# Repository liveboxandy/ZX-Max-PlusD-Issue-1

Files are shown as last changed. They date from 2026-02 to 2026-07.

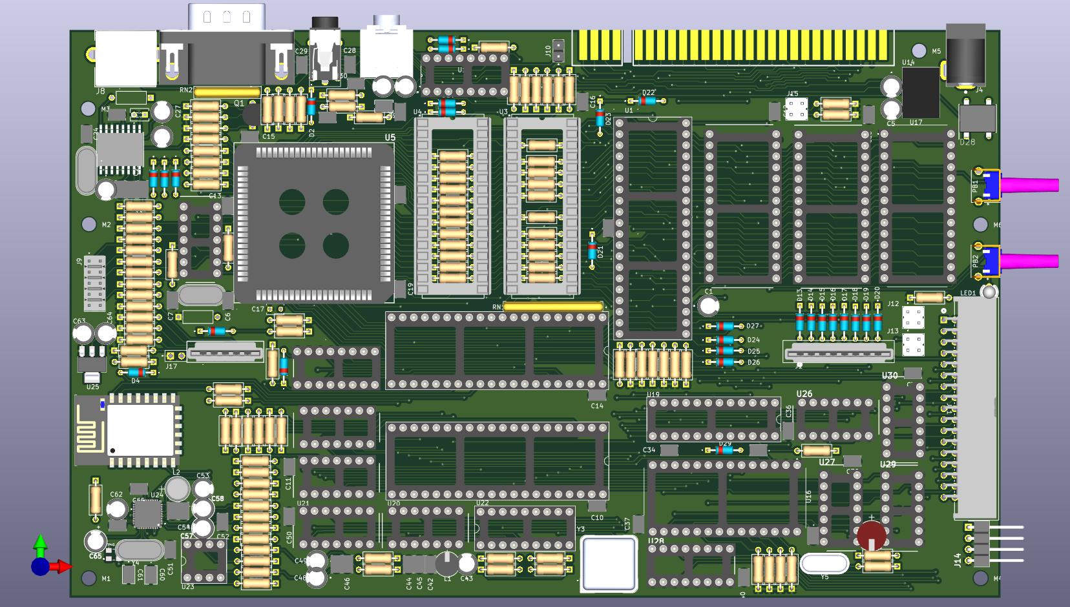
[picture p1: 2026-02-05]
ZX Max 128 PlusD Issue1.jpg

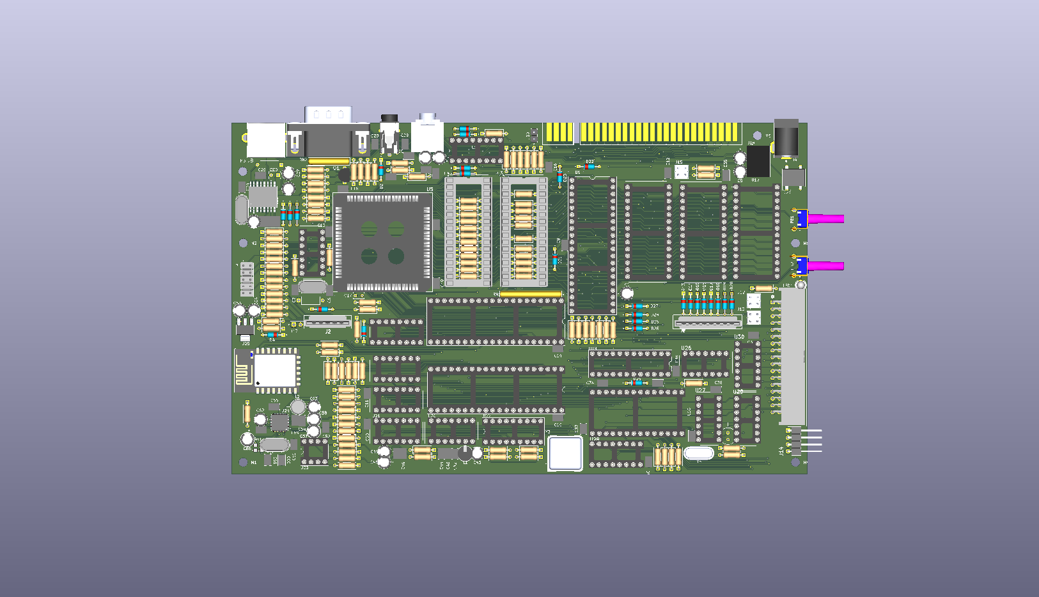
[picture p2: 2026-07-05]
ZX Max 128 PlusD Issue1.png

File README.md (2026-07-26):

This is a recreation of the ZX Max Plus D Issue 1 PCB as designed by DonSuperfo but done in KiCAD 10.

This was only done in order to create an interactive BOM (in the BOM folder) to assist in the assembling of the PCB.

The KiCAD schematics 'should' be correct but nothing should be assumed as correct without checking with the original schematic and PCB layout. Although I have followed the original track and via layout further checking should be done before using these files to order a pcb with. Currently I would still order the pcb from PCBWay using the link from https://github.com/DonSuperfo/ZX-Max-128

Note that any part number for any device used in this project might not be the correct one from the original BOM as supplied from PCBWay as I had to change some parts to get a footprint that would fit in the space on the original pcb with the correct pin spacing. This required selecting a different part number or vendor. This applies mainly to capacitors. Some other parts are no longer available under that number from Digikey.

As always, measure twice and order one.

Use at your own risk.

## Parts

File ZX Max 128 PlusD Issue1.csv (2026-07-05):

Source: | E:\Kicad\ZX Max 128 PlusD\ZX Max 128 PlusD Issue1.kicad_sch
Date: | 2026-07-05T10:47:33
Tool: | Eeschema 10.0.4
Generator: | C:\Program Files\KiCad\7.0\bin\scripting\plugins/bom_csv_grouped_by_value_with_fp.py
Component Count: | 266
Ref | Qnty | Value | Cmp name | Footprint | Description | Vendor | DNP
C1, C2, C3, C4, C26, C48, C49, C53, C62, C63, C64 | 11 | 10uF 25V | ECA-1EM100B | Mod:CAPPRD200W50D500H1100 | ECA-1EM100B - 10uF Aluminum Electrolytic Capacitors Radial
C5, C43 | 2 | 22uF 16V | ECA-1EM100B | Mod:CAPPRD200W50D500H1100 | ECA-1EM100B - 10uF Aluminum Electrolytic Capacitors Radial
C6, C7 | 2 | 27pF | FG18C0G1H270JNT06 | Mod:CAPRB250W50L400T250H550
C8, C27 | 2 | 220uF 16V | 16YXJ220MT16.3X11 | Mod:CAPPRD200W50D500H1100
C9, C10, C11, C12, C13, C14, C15, C16, C17, C18, C19, C20, C21, C22, C23, C24, C25, C28, C29, C30, C34, C35, C36, C37, C38, C39, C40, C42, C50, C51, C52, C54, C55, C56, C59 | 35 | 100nF | K104Z15Y5VF5TL2 | Mod:CAPRB250W50L400T250H550 | Vishay K 100nF Ceramic Multilayer Capacitor, 100 V dc, +85C, Y5V Dielectric, +80 %, -20 %
C31, C44, C45, C46, C47 | 5 | 10nF 50V | K104Z15Y5VF5TL2 | Mod:CAPRB250W50L400T250H550 | Vishay K 100nF Ceramic Multilayer Capacitor, 100 V dc, +85C, Y5V Dielectric, +80 %, -20 %
C32 | 1 | 3n3 50V | K104Z15Y5VF5TL2 | Mod:CAPRB250W50L400T250H550 | Vishay K 100nF Ceramic Multilayer Capacitor, 100 V dc, +85C, Y5V Dielectric, +80 %, -20 %
C33 | 1 | 3n3 50V | K104Z15Y5VF5TL2 | Mod:CAPRB250W50L400T250H550 | Vishay K 100nF Ceramic Multilayer Capacitor, 100 V dc, +85C, Y5V Dielectric, +80 %, -20 % |  | DNP
C41 | 1 | 33pF 100V | K330J10C0GH5TL2 | Mod:K101J15C0GF53L2 | Capacitor 33pF 100V
C57, C58 | 2 | 100uF 16V | WCAP-ATG8_5X11 | Mod:WCAP-ATG8_5X11_DXL_
C60, C61 | 2 | 22pF 50V | K220J15C0GF53L2 | Mod:CAP_K220J15C0GF53L2_VIS
C65 | 1 | 1uF 63V | WCAP-ATG5_5X11 | Mod:WCAP-ATG5_5X11_DXL_ | Capacitor 1uF 63V
C66 | 1 | 100pF 50V | K101J15C0GF53L2 | Mod:K101J15C0GF53L2 | Capacitor 100pF 50V
C67 | 1 | 100uF 35V | 35YXJ100M6.3X11 | Mod:CAP_YX_6P3X11_RUB | Capacitor 100uF 35V
D1, D2, D4, D5, D6, D7, D8, D9, D10, D11, D12, D13, D14, D15, D16, D17, D18, D19, D20, D21, D22, D23, D24, D25, D26, D27, D29 | 27 | 1N4148 | 1N4148 | Mod:DIOAD753W49L380D172B | Diode 1N4148
D28 | 1 | DF02M | DF02M | Mod:DIP825W58P510L832H543Q4N | Bridge Rectifier DF02M 1A
J1 | 1 | 8 Pin FFC Connector | 5-520315-8 | Mod:55203155 | Connector FFC Socket 8 Pin
J2 | 1 | 5 Pin FFC Connector | 5-520315-5 | Mod:55203155 | Connector FFC Socket 5 Pin
J3 | 1 | ZX_48K_EDGE | ZX_48K_EDGE | Mod:ZX_BUS_B_TOP | ZX Spectrum 48K Edge Connector
J4 | 1 | PJ-002A | PJ-002A | Mod:CUI_PJ-002A
J5 | 1 | AV Jack | AudioJack3 | Mod:PJ-322A | AV Jack PJ-322
J6 | 1 | Connector Audio 3525N | SJ1-3525N | Mod:CUI_SJ1-3525N | Connector Audio 3525N
J7 | 1 | A-DS_09_A_KG-T4S | A-DS_09_A_KG-T4S | Mod:ASSMANN_A-DS_09_A_KG-T4S | 9-pin D-SUB connector, pins (male), Mounting Hole
J8 | 1 | Connector 9 Pin Mini DIN | KMDGX-9S-BS-1 | Mod:KMDGX9SBS1 | Connector 9 Pin MiniDin
J9 | 1 | Header 5x2 | 10129381-910002BLF | Mod:AMPHENOL_10129381-910002BLF | Header 5x2
J10, J17 | 2 | Header 2x1 | M20-9990246 | Mod:HARWIN_M20-9990246
J11 | 1 | FDC Connector | 5103311-7 | Mod:CONN_5103311-7_TYC | Connector 17x2 RA
J12, J13 | 2 | Header 2x2 | PH2-04-UA | Mod:ADAM_PH2-04-UA | Header 2x2
J14 | 1 | Header 4 Pin FDD Power | SWR25X-NRTC-S04-RB-BA | Mod:HDRRA4W64P0X254_1X4_1016X320X610P | Header 4 Pin FDD Power
J15 | 1 | PlusD ROM | PH2-04-UA | Mod:ADAM_PH2-04-UA | Header 2x2
L1, L2 | 2 | 220uH | RLB0608-221KL | Mod:IND_BOURNS_RLB0608
LED1 | 1 | LED Red 3MM | WL-TMRC_3MM | Mod:WL-TMRC_3MM | LED Red 3MM
PB1 | 1 | Switch 6x6 RA | 2-1825027-0 | Mod:SW2_1825027-G_TEC
PB2 | 1 | NMI | 2-1825027-0 | Mod:SW2_1825027-G_TEC | Switch 6mm x 6mm RA
Q1 | 1 | Transistor BC548 | BC548BTA | Mod:BC548BTA
R1, R2, R3, R4, R5, R6, R7, R8, R9, R10, R11, R12, R13, R14, R15, R16, R17, R18, R19, R20, R21, R22, R27, R28, R29, R54, R57, R58, R78, R81, R82, R83, R84, R85, R86 | 35 | 470R | CF14JT470R | Mod:STA_CF14_STP | 470R
R23, R24, R25, R26, R46, R47, R48, R49, R50, R55, R56, R73, R75, R77, R79, R80, R92, R93, R96, R97, R100, R103, R112 | 23 | 10K0 | CF14JT10K0 | Mod:STA_CF14_STP | 10K0
R30, R31, R32, R33 | 4 | 75R0 | CF14JT75R0 | Mod:STA_CF14_STP | 75R0
R34 | 1 | 2K70 | CF14JT2K70 | Mod:STA_CF14_STP | 2K70 |  | DNP
R35, R36, R37, R38, R39 | 5 | 68R0 | CF14JT68R0 | Mod:STA_CF14_STP | 68R0
R40, R41, R42, R43, R44, R45 | 6 | 150R | CF14JT150R | Mod:STA_CF14_STP | 150R
R51 | 1 | 1M00 | CF14JT1M00 | Mod:STA_CF14_STP | 1M00
R52, R59, R62, R63, R64, R65, R68, R69, R70, R94, R95, R98, R99 | 13 | 1K00 | CF14JT1K00 | Mod:STA_CF14_STP | 1K00
R53 | 1 | 4K70 | CF14JT4K70 | Mod:STA_CF14_STP | 4K70 |  | DNP
R60, R61, R66, R67, R90, R91, R102, R105 | 8 | 2K20 | CF14JT2K20 | Mod:STA_CF14_STP | 2K20
R71 | 1 | 33K0 | CF14JT33K0 | Mod:STA_CF14_STP | 33K0
R72, R74 | 2 | 150K | CF14JT150K | Mod:STA_CF14_STP | 150K
R76 | 1 | 470K | CF14JT470K | Mod:STA_CF14_STP | 470K
R87, R88 | 2 | 270R | CF14JT270R | Mod:STA_CF14_STP | 270R
R101, R104, R108, R109 | 4 | 24K0 | CF14JT24K0 | Mod:STA_CF14_STP | 24K0
R106, R110, R111 | 3 | 47K0 | CF14JT47K0 | Mod:STA_CF14_STP | 47K0
R107 | 1 | 27K0 | CF14JT27K0 | Mod:STA_CF14_STP | 27K0
RN1 | 1 | 10K | 4609X-101-103LF | Mod:SIP249W50P254L2281H508Q9
RN2 | 1 | 10K | 4606X-101-103LF | Mod:4606X-101-103LF
U1 | 1 | Z80 | Z84C0010PEG | Mod:Z80_Socket | Z80 CPU
U2, U18 | 2 | EEPROM/EPROM 32Kx8 | AT27C256R-45PU | Mod:DIP1556W56P254L3702H483Q28N | EEPROM/EPROM 32Kx8
U3, U4 | 2 | AS6C1008-55PCN | AS6C1008-55PCN | Mod:PDIP-32_MIL600_ALL
U5 | 1 | EPM7128SLC | PLCC-84-AT | Mod:PLCC84AT | EPM7128SLC-84 PLCC Socket
U6 | 1 | 74HC04 | 74HC04_1 | Mod:DIP794W53P254L1930H508Q14N | Hex Inverter
U7 | 1 | SN74HC174N | SN74HC174N | Mod:DIP794W53P254L1930H508Q16N | Hex D flip-flop w/reset,SN74HC174N DIP16
U8, U9 | 2 | AY-3-8910 | AY-3-8910_1 | Mod:Z80_Socket | AY-3-8910 Sound Synth
U10, U20 | 2 | CD74HC30E | CD74HC30E_1 | Mod:DIP794W53P254L1930H508Q14N | NAND, 8-Input
U11 | 1 | 74HC74 | 74HC74 | Mod:DIP794W53P254L1930H508Q14N | Dual D Flip-flop, Set & Reset
U12 | 1 | CD74HC366E | CD74HC366E | Mod:CD74HC366E | Hex Buffer Inverting Tri-State
U13 | 1 | AD724JRZ | AD724JRZ | Mod:RW_16_ADI | RGB - PAL Encoder
U14 | 1 | R-78E5.0-1.0 | R-78E5.0-1.0 | Mod:CONV_R-78E5.0-1.0
U15 | 1 | ESP8266-12E | ESP8266-12E | Mod:WIFI_Module_ESP8266_12E | ESP8266-12E Bluetooth Module
U16 | 1 | WD1772 | WD1772 | Mod:DIP1555W45P254L3733H482Q28
U17 | 1 | AS6C6264-55PCN | AS6C6264-55PCN | Mod:DIP1555W45P254L3733H482Q28 | SRAM 64Kx8
U19 | 1 | GAL20V8B | GAL20V8B | Mod:DIP-24_W7.62mm_Socket | Hex D FlipFlop
U21 | 1 | 74HC32 | 74HC32 | Mod:DIP794W53P254L1930H508Q14N
U22 | 1 | Sound Generator SAA1099 | SAA1099 | Mod:DIP-18_W7.62mm_Socket | Sound Generator SAA1099
U23 | 1 | MCP602-I/P | MCP602 | Mod:DIP-8_W7.62mm_Socket | MCP602-I/P Dual Op Amp 8 Pin
U24 | 1 | SAM2695 | SAM2695 | Mod:QFN40P600X600X90-49N | MIdi Generator SAM2695
U25 | 1 | 3V3 1Amp | AZ1117IH-3.3TRG1 | Mod:SOT230P700X185-4N | Voltage Regulator 3V3 1Amp
U26 | 1 | 74HC27 | 74HC27 | Mod:DIP794W53P254L1930H508Q14N | NOR, 3-Input, Triple
U27 | 1 | 74HC00 | 74HC00 | Mod:DIP794W53P254L1930H508Q14N | NAND, 2-Input, Quad
U28 | 1 | SN74LS175NE4 | SN74LS175NE4 | Mod:DIP794W53P254L1930H508Q16N | Flip Flops Quadruple D-Type Flip-Flop W/Clear
U29 | 1 | SN74LS06 | SN74LS06 | Mod:DIP794W53P254L1930H508Q14N | Hex Inverter
U30 | 1 | 74HC126 | 74HC126 | Mod:DIP794W53P254L1930H508Q14N | Buffer, Quad, 3-State
Y1 | 1 | 28.375Mhz | Crystal | Mod:Crystal_HC49-4H_Vertical | Two pin crystal
Y2 | 1 | 4.433Mhz | Crystal | Mod:Crystal_HC49-4H_Vertical | Two pin crystal
Y3 | 1 | ECS-2100A-080 | ECS-2100A-080 | Mod:OSC_ECS-2100A-080 | Crystal 4 Pin 8Mhz
Y4 | 1 | 12Mhz | Crystal | Mod:Crystal_HC49-4H_Vertical | Two pin crystal
Y4x1 | 1 | 12Mhz | ECS-2333-120-BN-TR | Mod:OSC_ECS-2333-120-BN-TR | Crystal 2 Pin 12Mhz
Y5 | 1 | Crystal 8Mhz | ATS08A-E | Mod:XTAL_HC49P488W43L1085T450H368 | Crystal 8Mhz

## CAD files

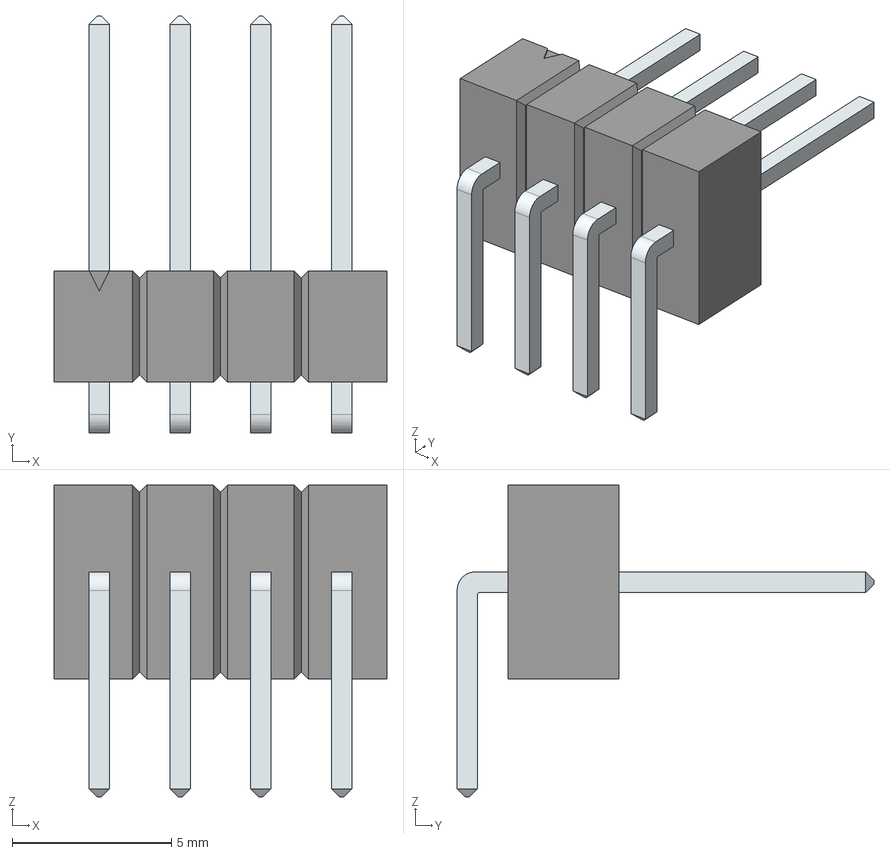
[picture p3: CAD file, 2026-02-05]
Step/Header 4x1 RA SWR25X-NRTC-S04-RB-BA.stp
10.5 x 13.1 x 9.80 mm
LeadsArray

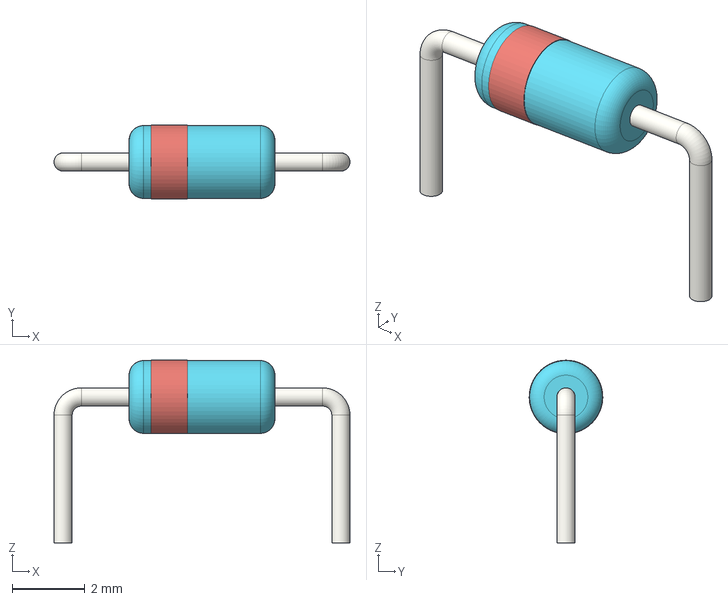
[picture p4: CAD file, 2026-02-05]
Step/D_DO-35_SOD27_P7.62mm_Horizontal.step
8.12 x 2.02 x 5.01 mm

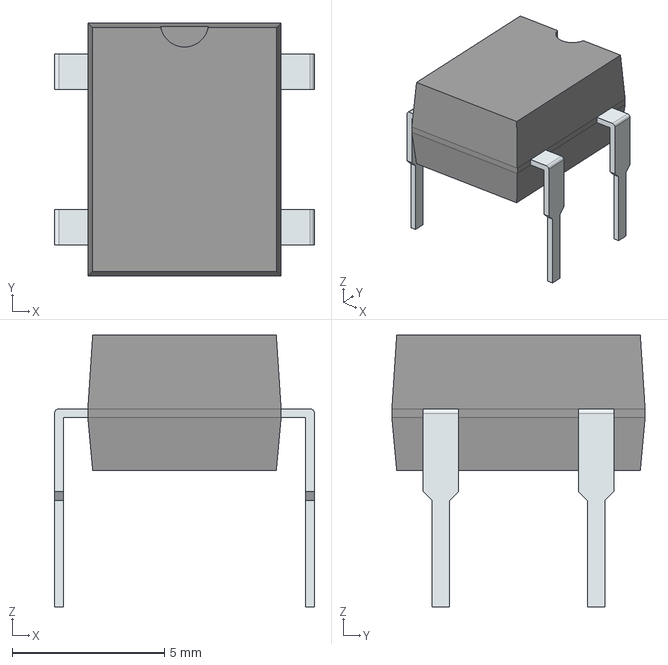
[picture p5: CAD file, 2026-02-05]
Step/Diode Bridge Rectifier DF02M.stp
8.54 x 8.32 x 8.93 mm
PinsArrayLR

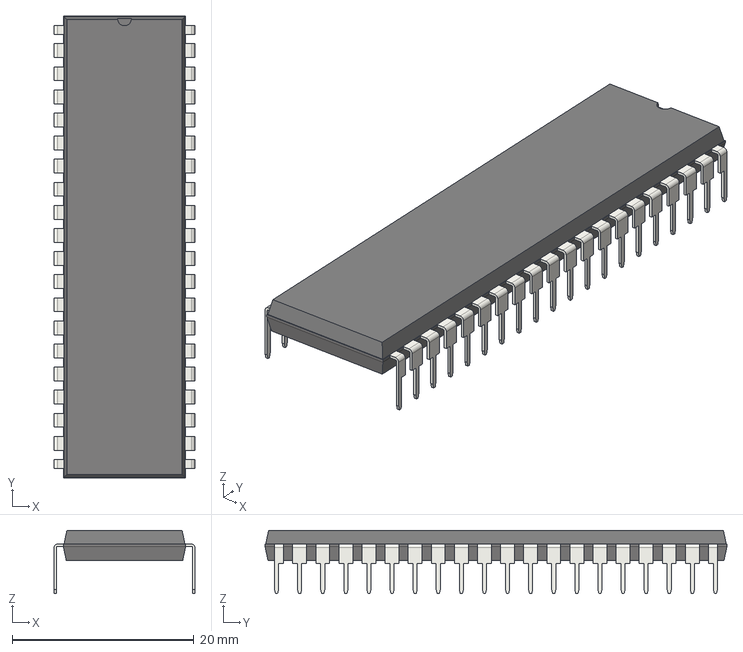
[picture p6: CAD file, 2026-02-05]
Step/DIP-40_W15.24mm.step
15.5 x 50.8 x 6.98 mm

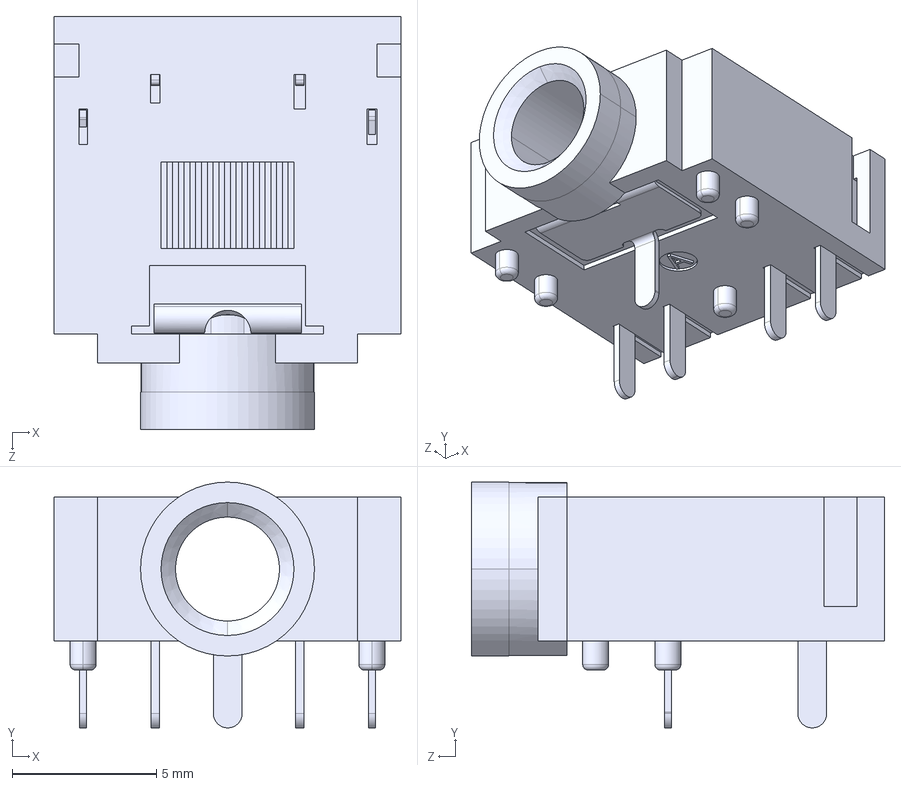
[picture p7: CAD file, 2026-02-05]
Step/Audio Connector SJ1-3525N.step
12.0 x 8.51 x 14.3 mm

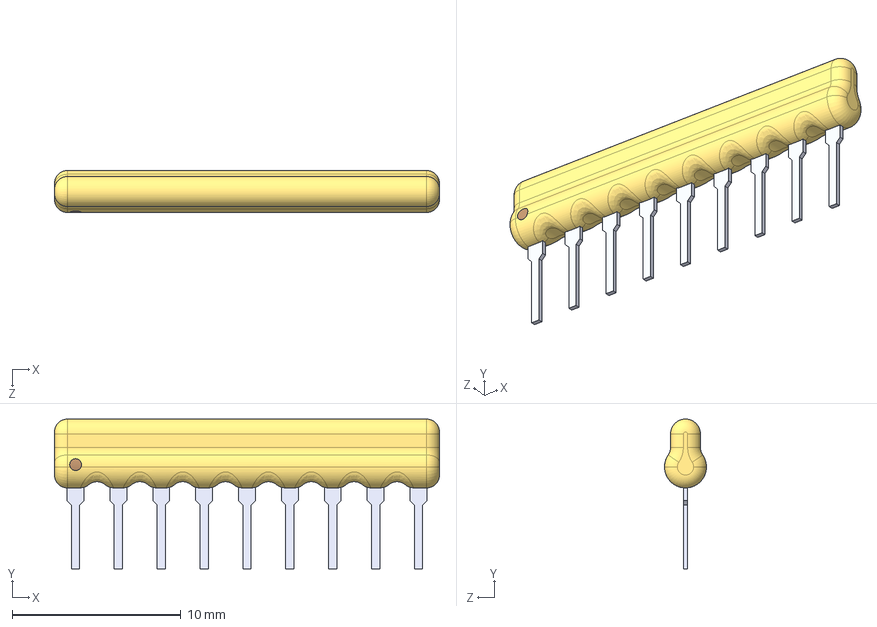
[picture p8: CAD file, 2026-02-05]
Step/RNET 10K 9PIn 4609X-101-103LF.step
22.8 x 8.88 x 2.49 mm

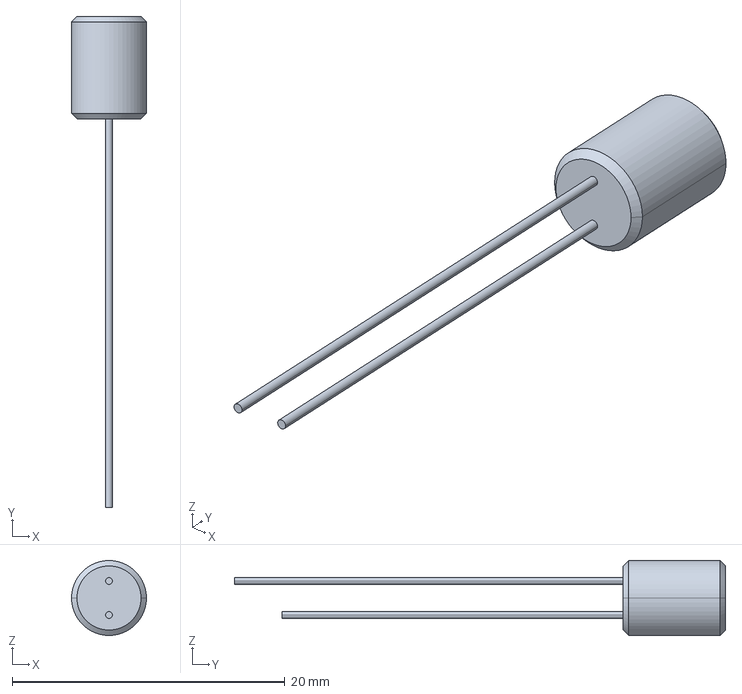
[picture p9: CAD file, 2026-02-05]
Step/Inductor rlb0608.stp
5.50 x 36.0 x 5.50 mm

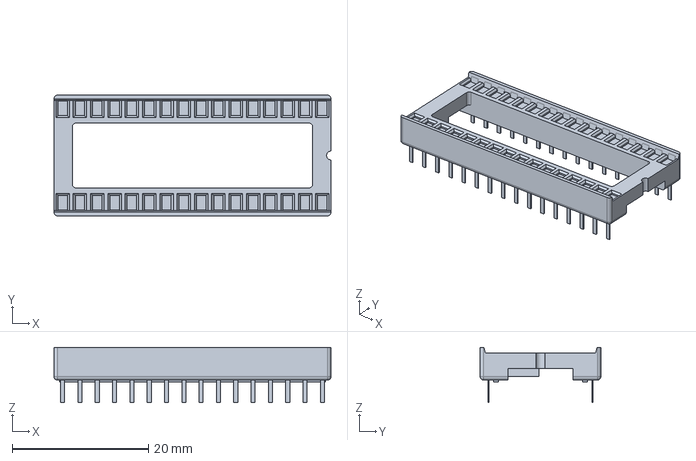
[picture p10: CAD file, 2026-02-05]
Step/DIP-32_W15.24mm_Socket-1.stp
40.6 x 17.7 x 8.10 mm

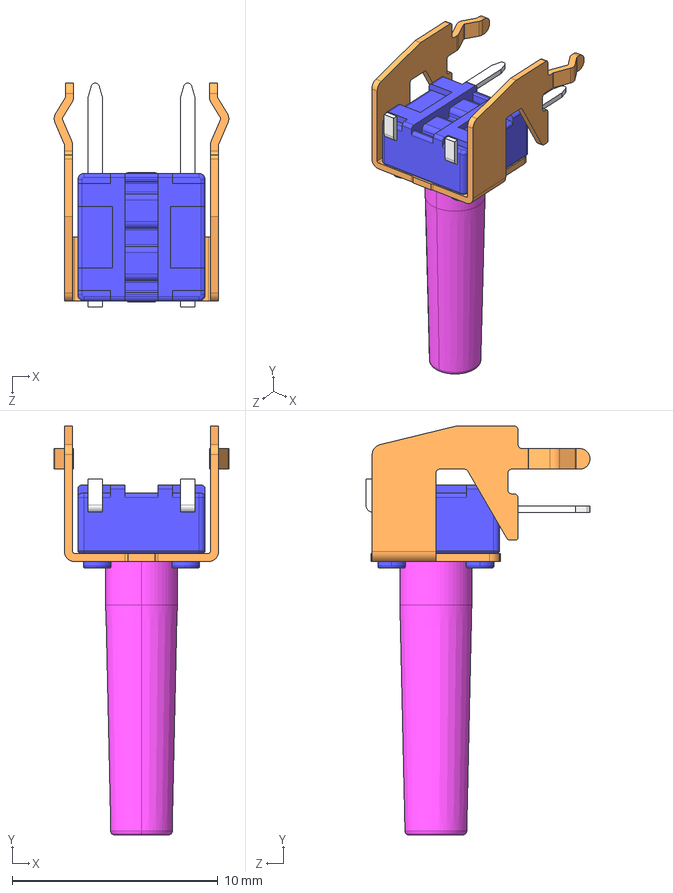
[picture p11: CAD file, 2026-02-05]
Step/Switch 6mm RA SKHHNHA010.stp
8.50 x 19.9 x 10.9 mm

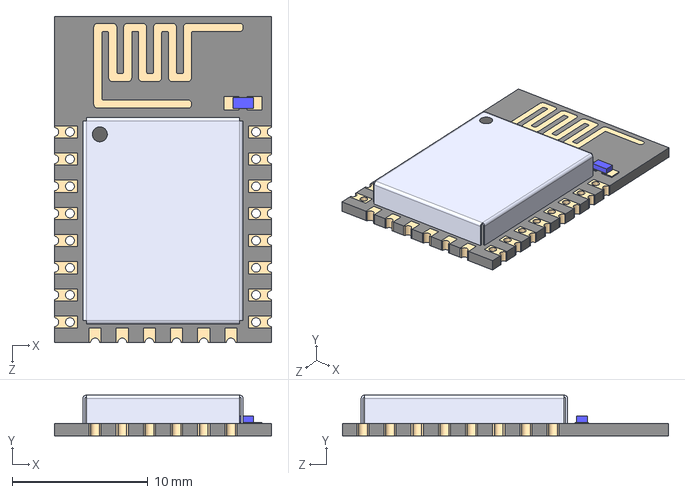
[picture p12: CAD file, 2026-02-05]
Step/ESP8266-12E_ESP-12E.step
16.0 x 3.00 x 24.0 mm

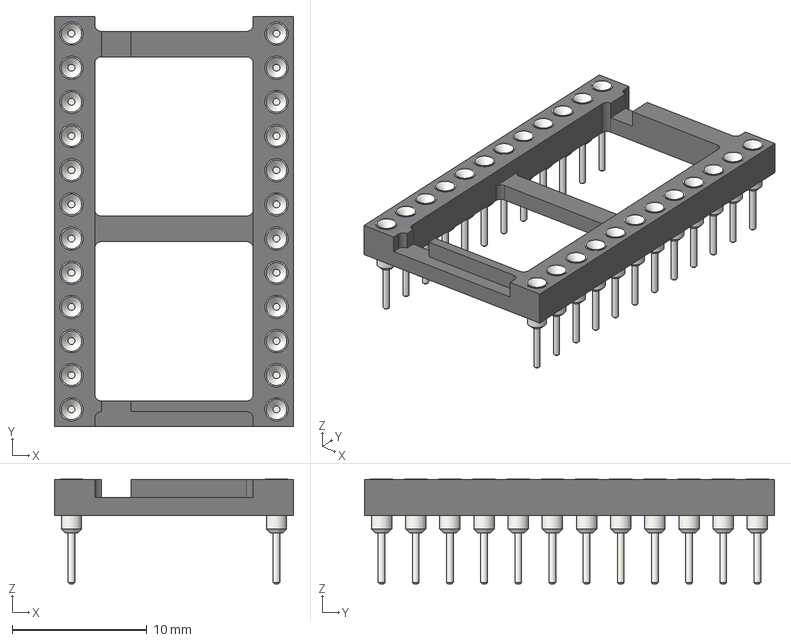
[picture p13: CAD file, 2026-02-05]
Step/DIP-24_W15.24mm_Socket.step
17.8 x 30.5 x 7.79 mm

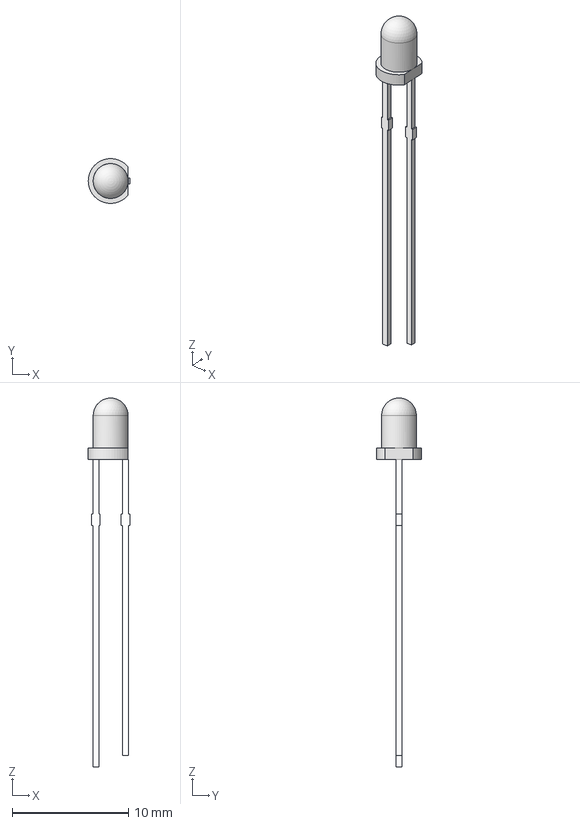
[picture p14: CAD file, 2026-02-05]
Step/LED Red 3mm WL-TMRC_3MM.step
3.57 x 3.85 x 31.7 mm

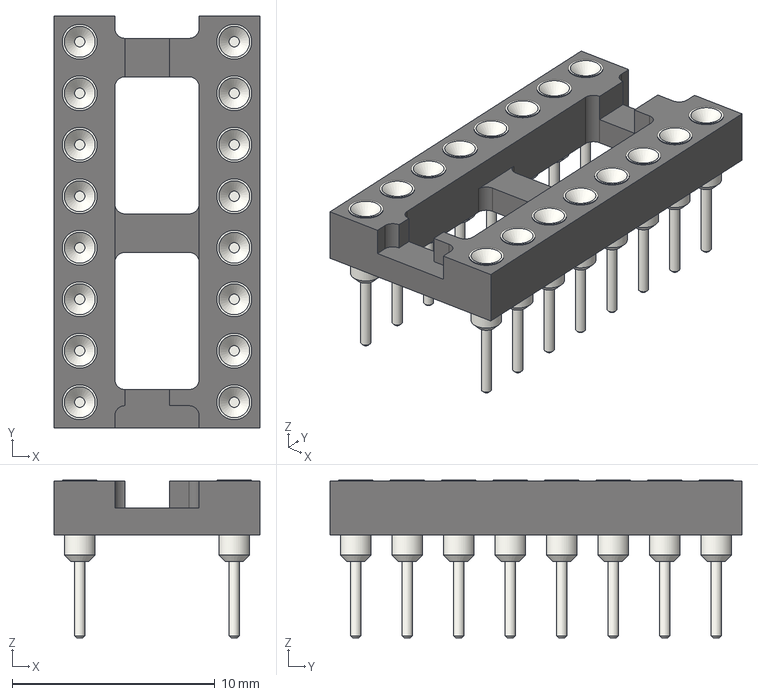
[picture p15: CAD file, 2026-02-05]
Step/DIP-16_W7.62mm_Socket.step
10.2 x 20.3 x 7.79 mm

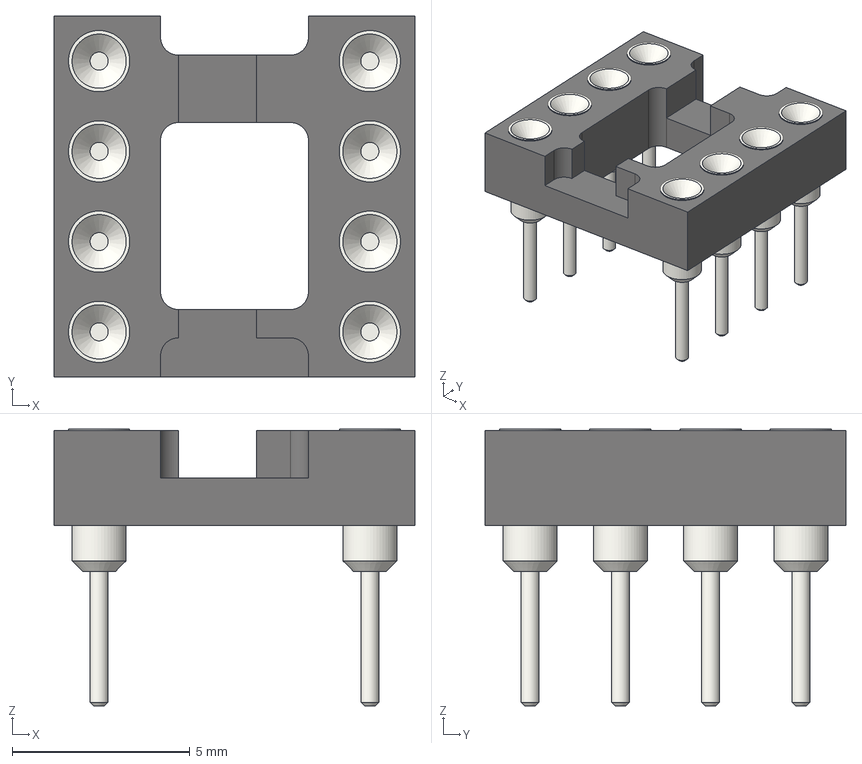
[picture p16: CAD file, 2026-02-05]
Step/DIP-8_W7.62mm_Socket.step
10.2 x 10.2 x 7.79 mm

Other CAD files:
Step/PJ-322.step
Step/PJ-002A.step
Step/DIP-28_W15.24mm_Socket.step
Step/DIP-16_W7.62mm.step
Step/9Pin D MRA Assmannn A-DS_09_A_KG-T4S.step
Step/9Pin MiniDIN KMDGX-9S-BS-1_A1.IGS
Step/ADI724JRZ RW_16_ADI.step
Step/Capacitor 100nF 50V MLCC K104Z15Y5VF5TL2.stp
Step/Capacitor 100pF 50V MLCC K101J15C0GF53L2.stp
Step/Capacitor 10uF 25V ECA-1EM100B.stp
Step/Capacitor 22uF 16V 5x7 EEAGA1C220H.step
Step/Connector 5 Way Keyboard CONN_5-520315-5.stp
Step/Connector 8 Way Keyboard CONN_5-520315-8_TYC.stp
Step/Connector Pin-Pin 1x2 M20-9990246.step
Step/Connector Pin-Pin 5x2 10129381-910002BLF.step
Step/Crystal TH 2 Pin.stp
Step/Crystal_HC49-4H_Vertical.step
Step/DIP-14_W7.62mm.step
Step/DIP-14_W7.62mm_Socket.step
Step/DIP-18_W7.62mm_Socket.step
Step/DIP-24_W7.62mm_Socket.step
Step/DIP-28_W15.24mm.step
Step/DIP-32_W15.24mm.step
Step/DIP-32_W15.24mm_Socket.step
Step/DIP-40_W15.24mm_Socket.step
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

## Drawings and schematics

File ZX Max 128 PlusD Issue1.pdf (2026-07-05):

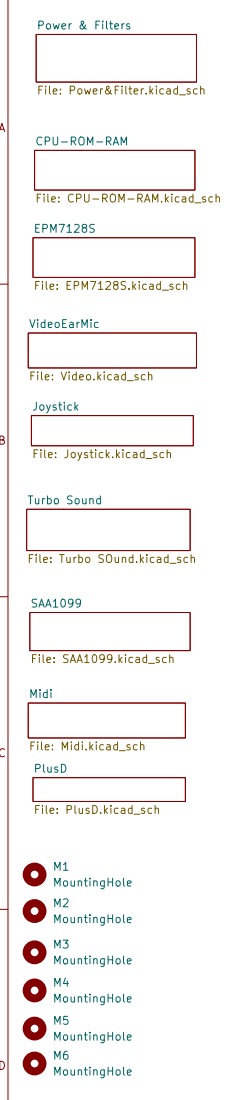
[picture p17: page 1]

File: EPM7128S.kicad_sch Power & Filters File: Power&Filter.kicad_sch M5 MountingHole M6 MountingHole M2 MountingHole M3 MountingHole M4 MountingHole M1 MountingHole
Joystick File: Joystick.kicad_sch CPU-ROM-RAM

File: CPU-ROM-RAM.kicad_sch

File: PlusD.kicad_sch Midi File: Midi.kicad_sch SAA1099

Sheet: /
File: ZX Max 128 PlusD Issue1.kicad_sch
Title:

Size: A4 | Rev:
KiCad E.D.A. 10.0.4 | Id: 1/10

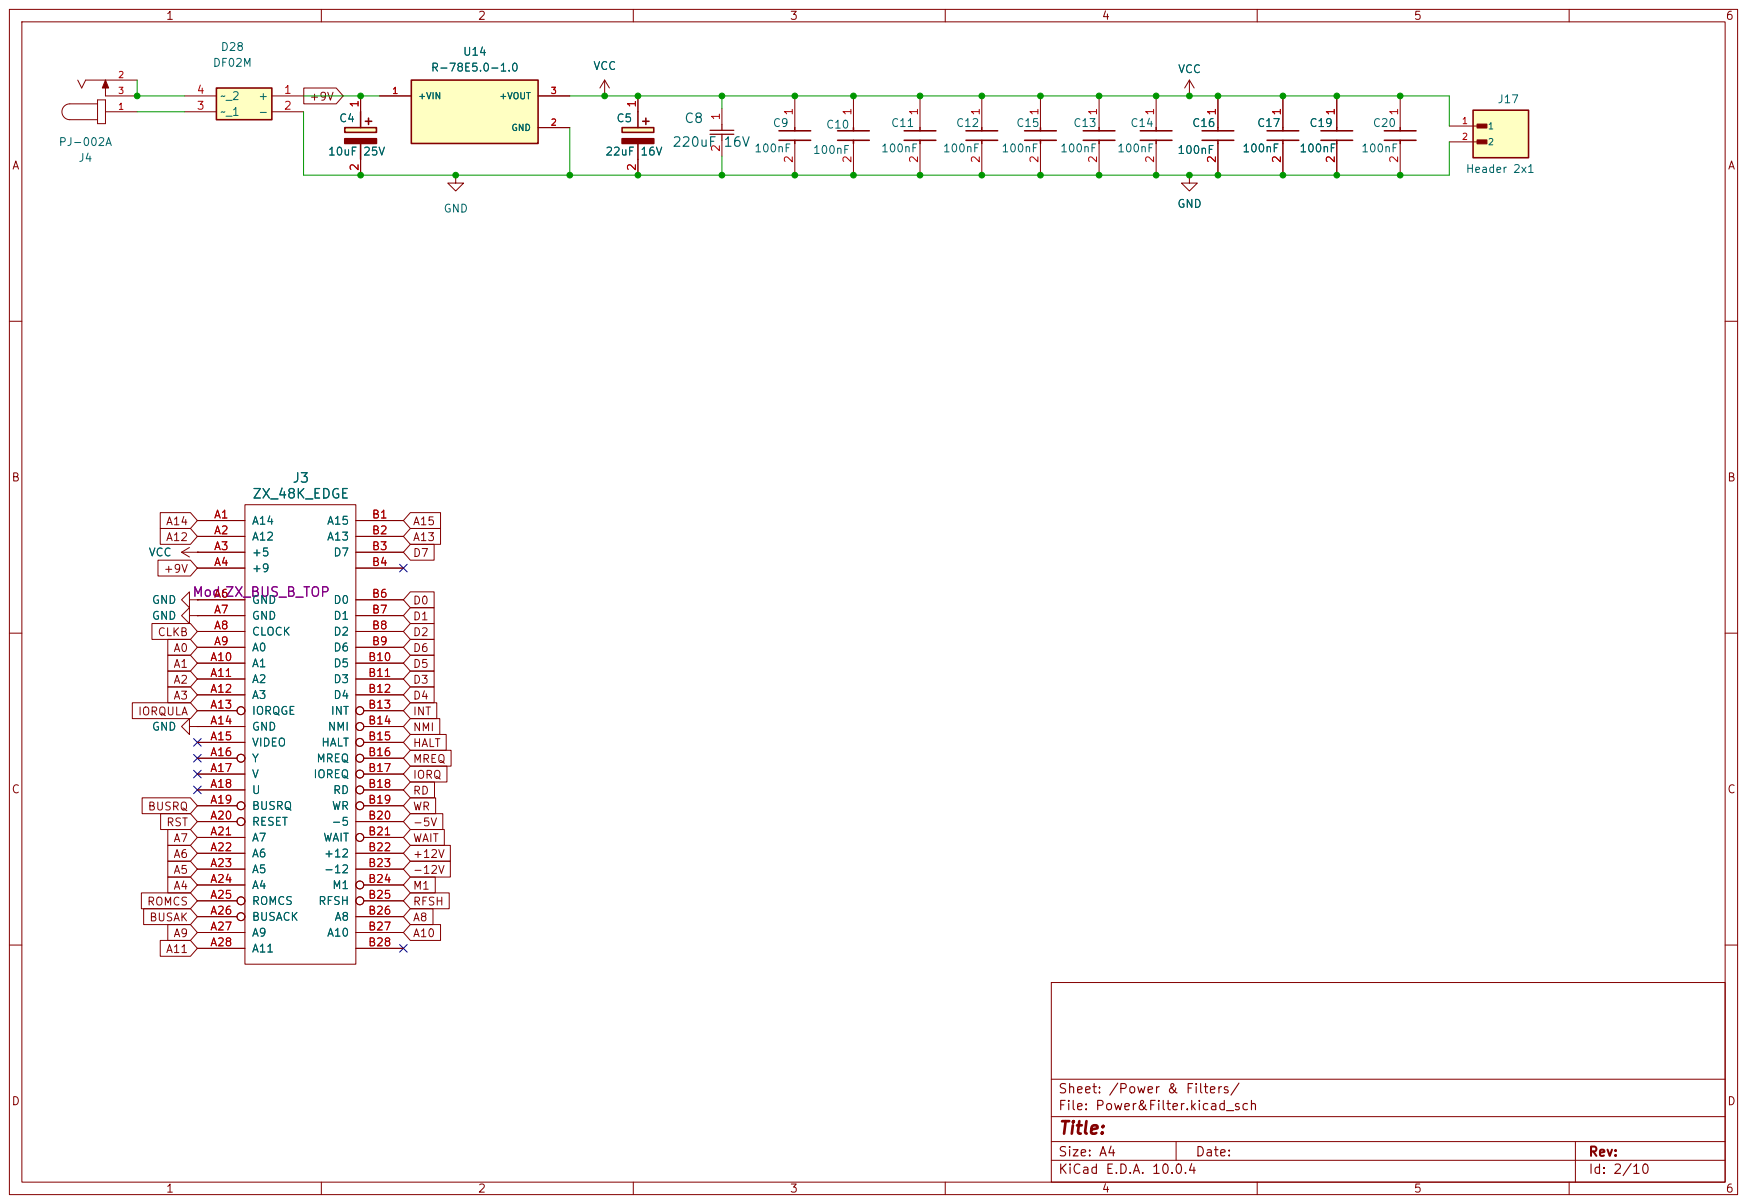
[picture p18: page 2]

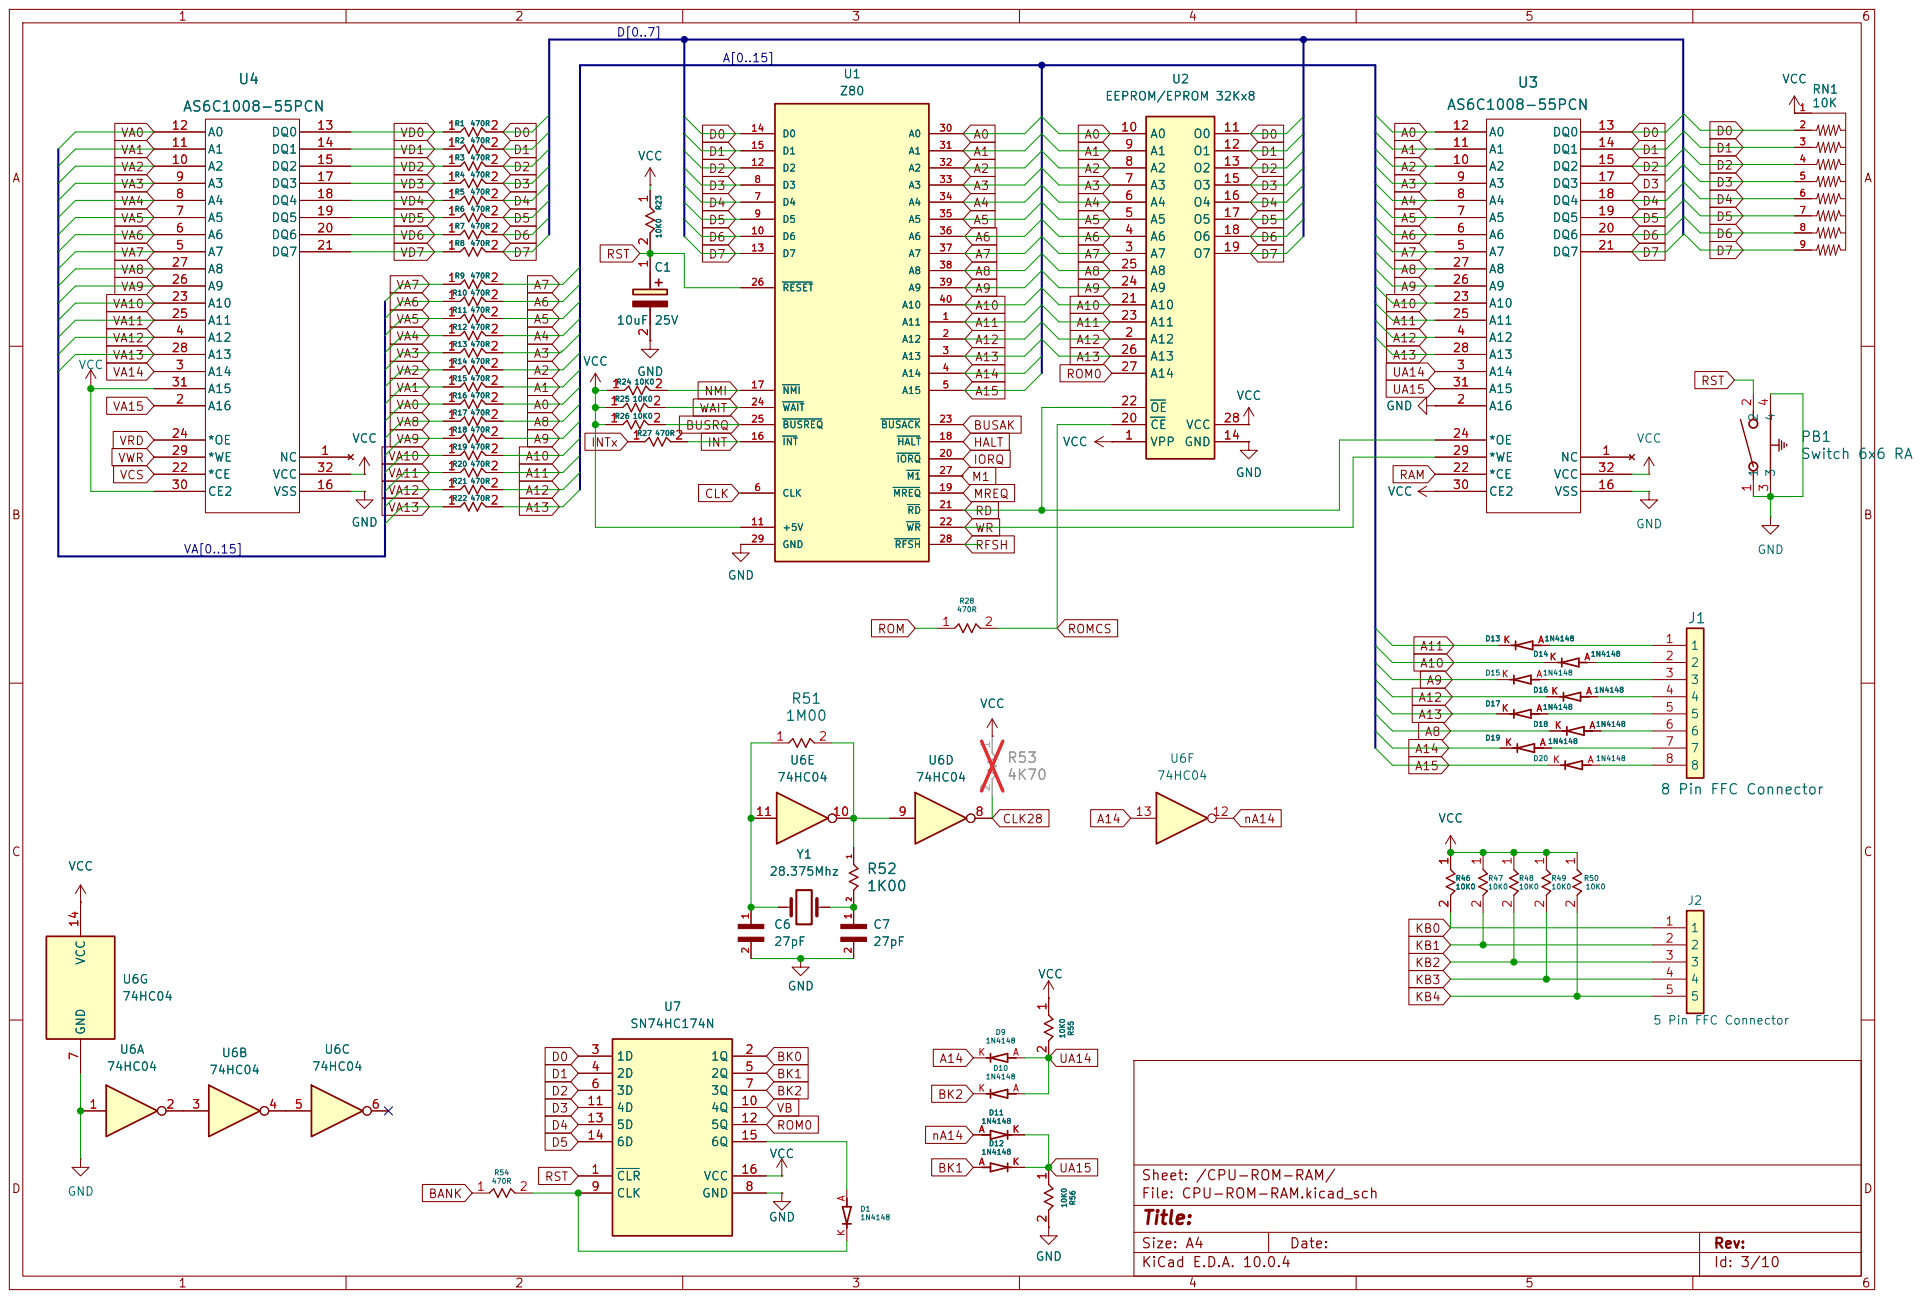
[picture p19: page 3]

Sheet: /CPU-ROM-RAM/
File: CPU-ROM-RAM.kicad_sch
Title:

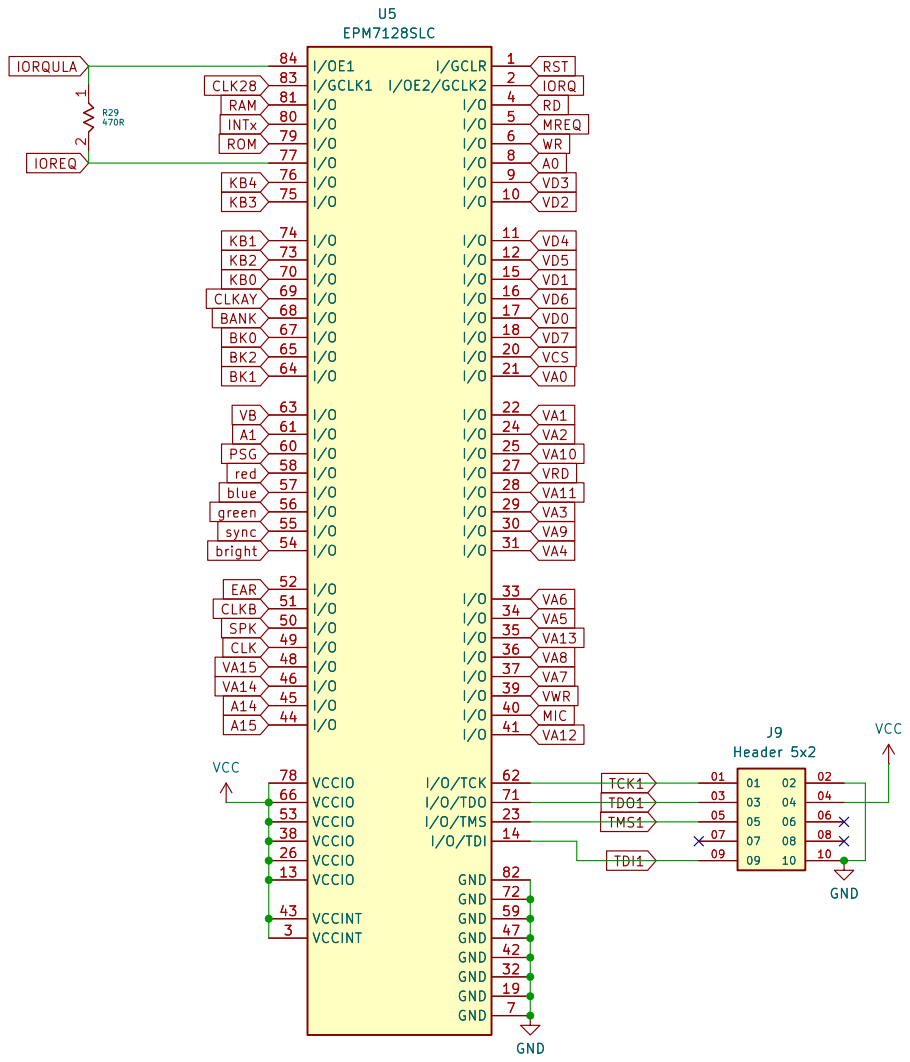
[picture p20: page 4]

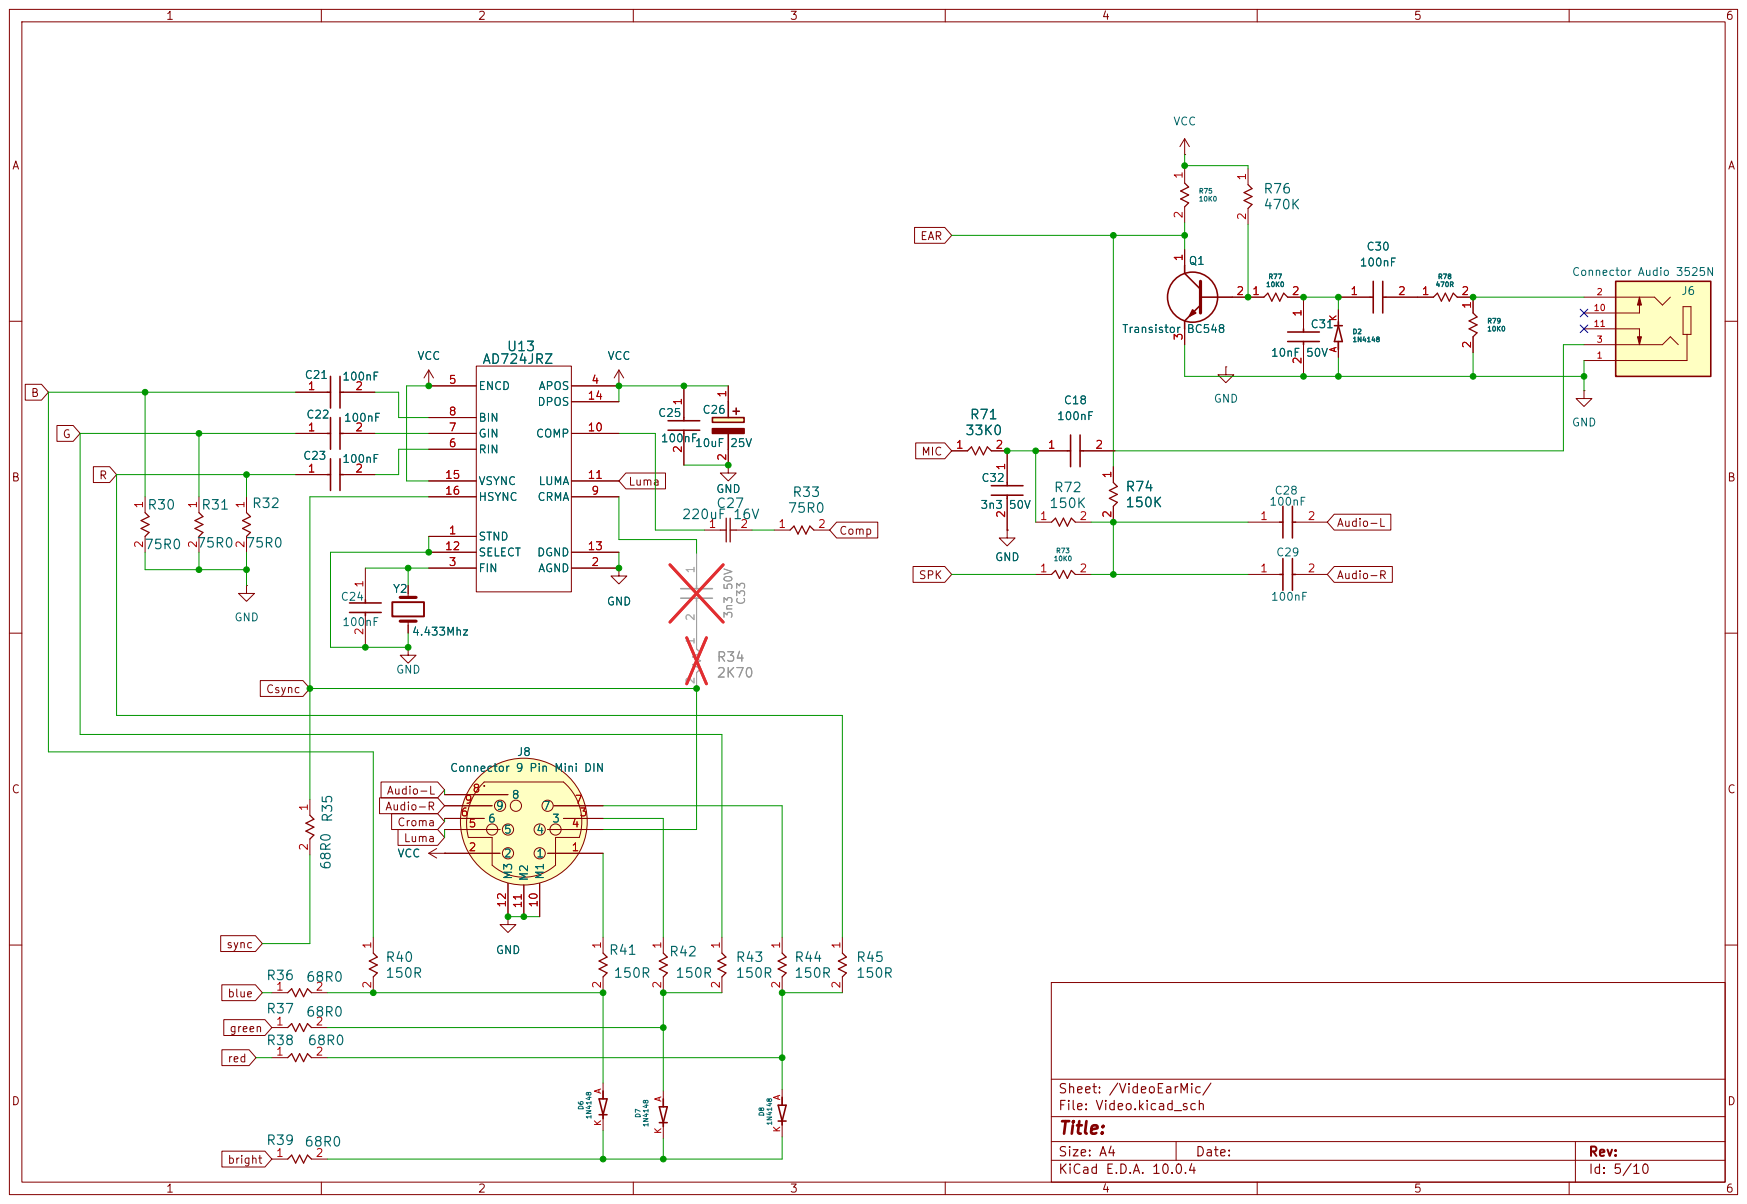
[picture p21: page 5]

J8 Connector 9 Pin Mini DIN

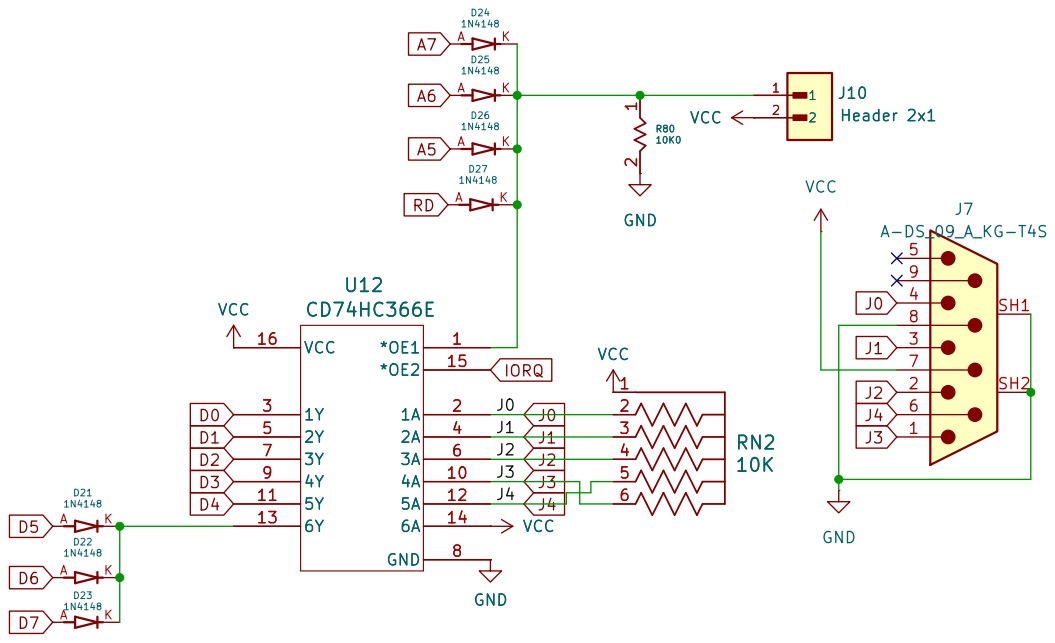
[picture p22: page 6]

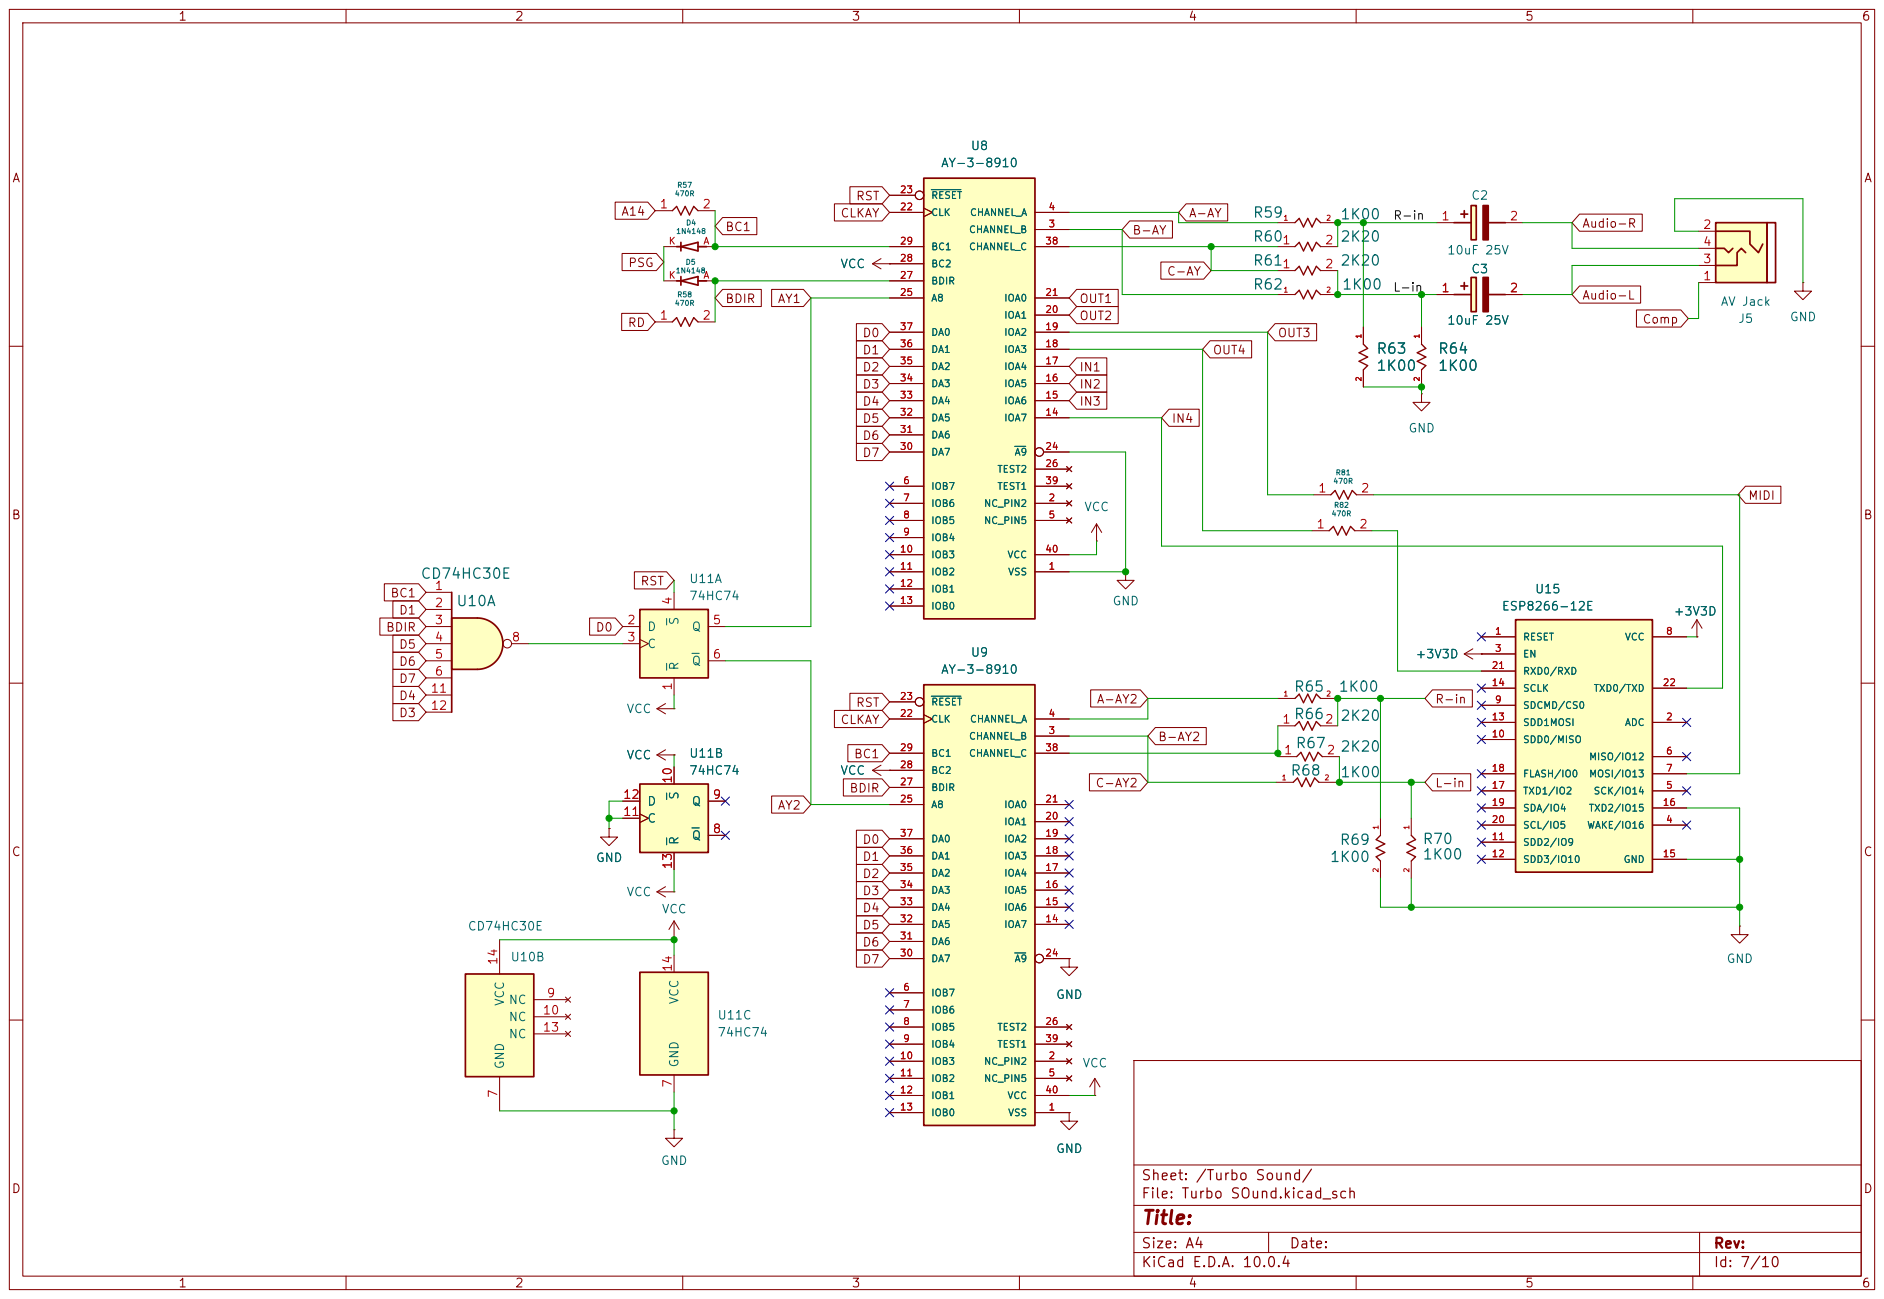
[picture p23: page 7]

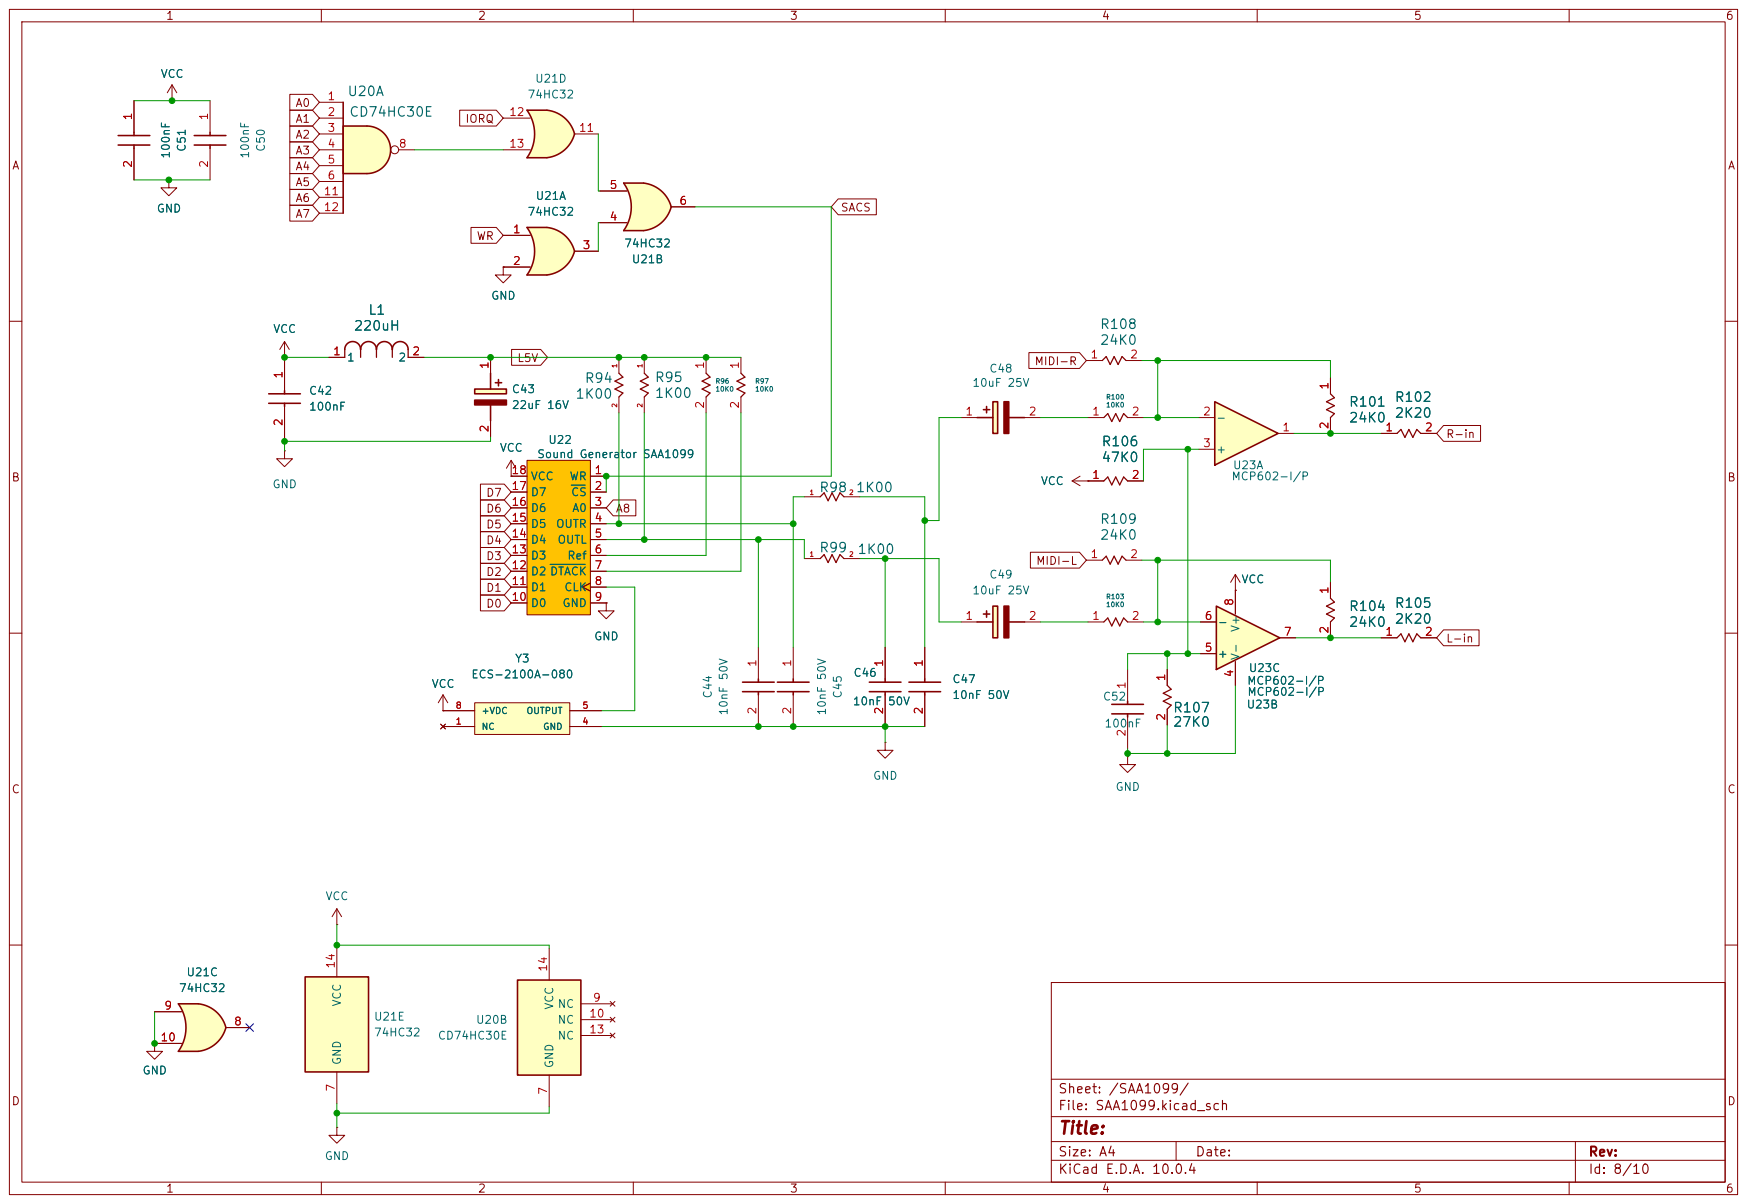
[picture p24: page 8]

7 NC 9 NC 10 NC 13 VCC 14 U20B

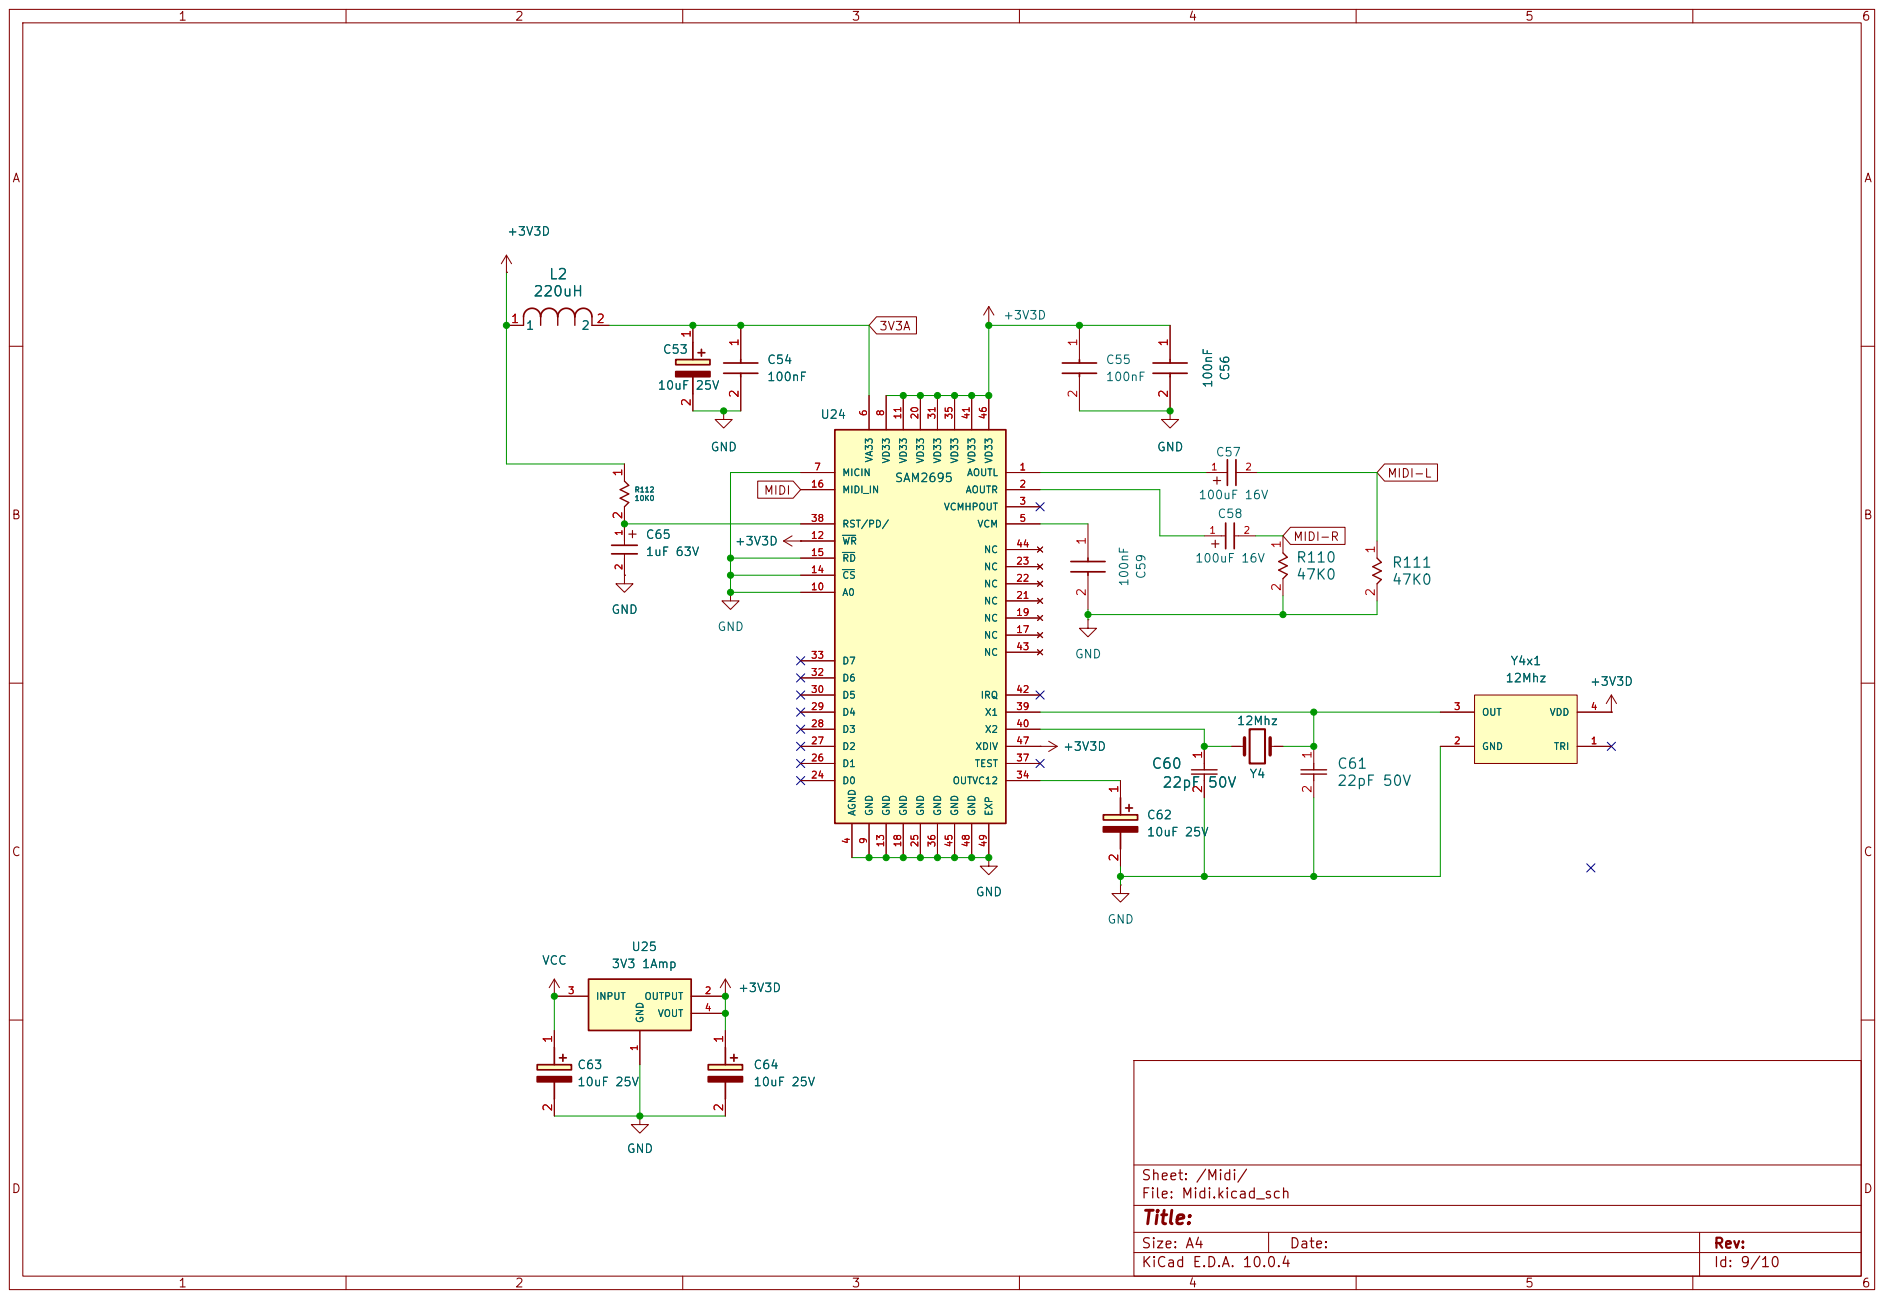
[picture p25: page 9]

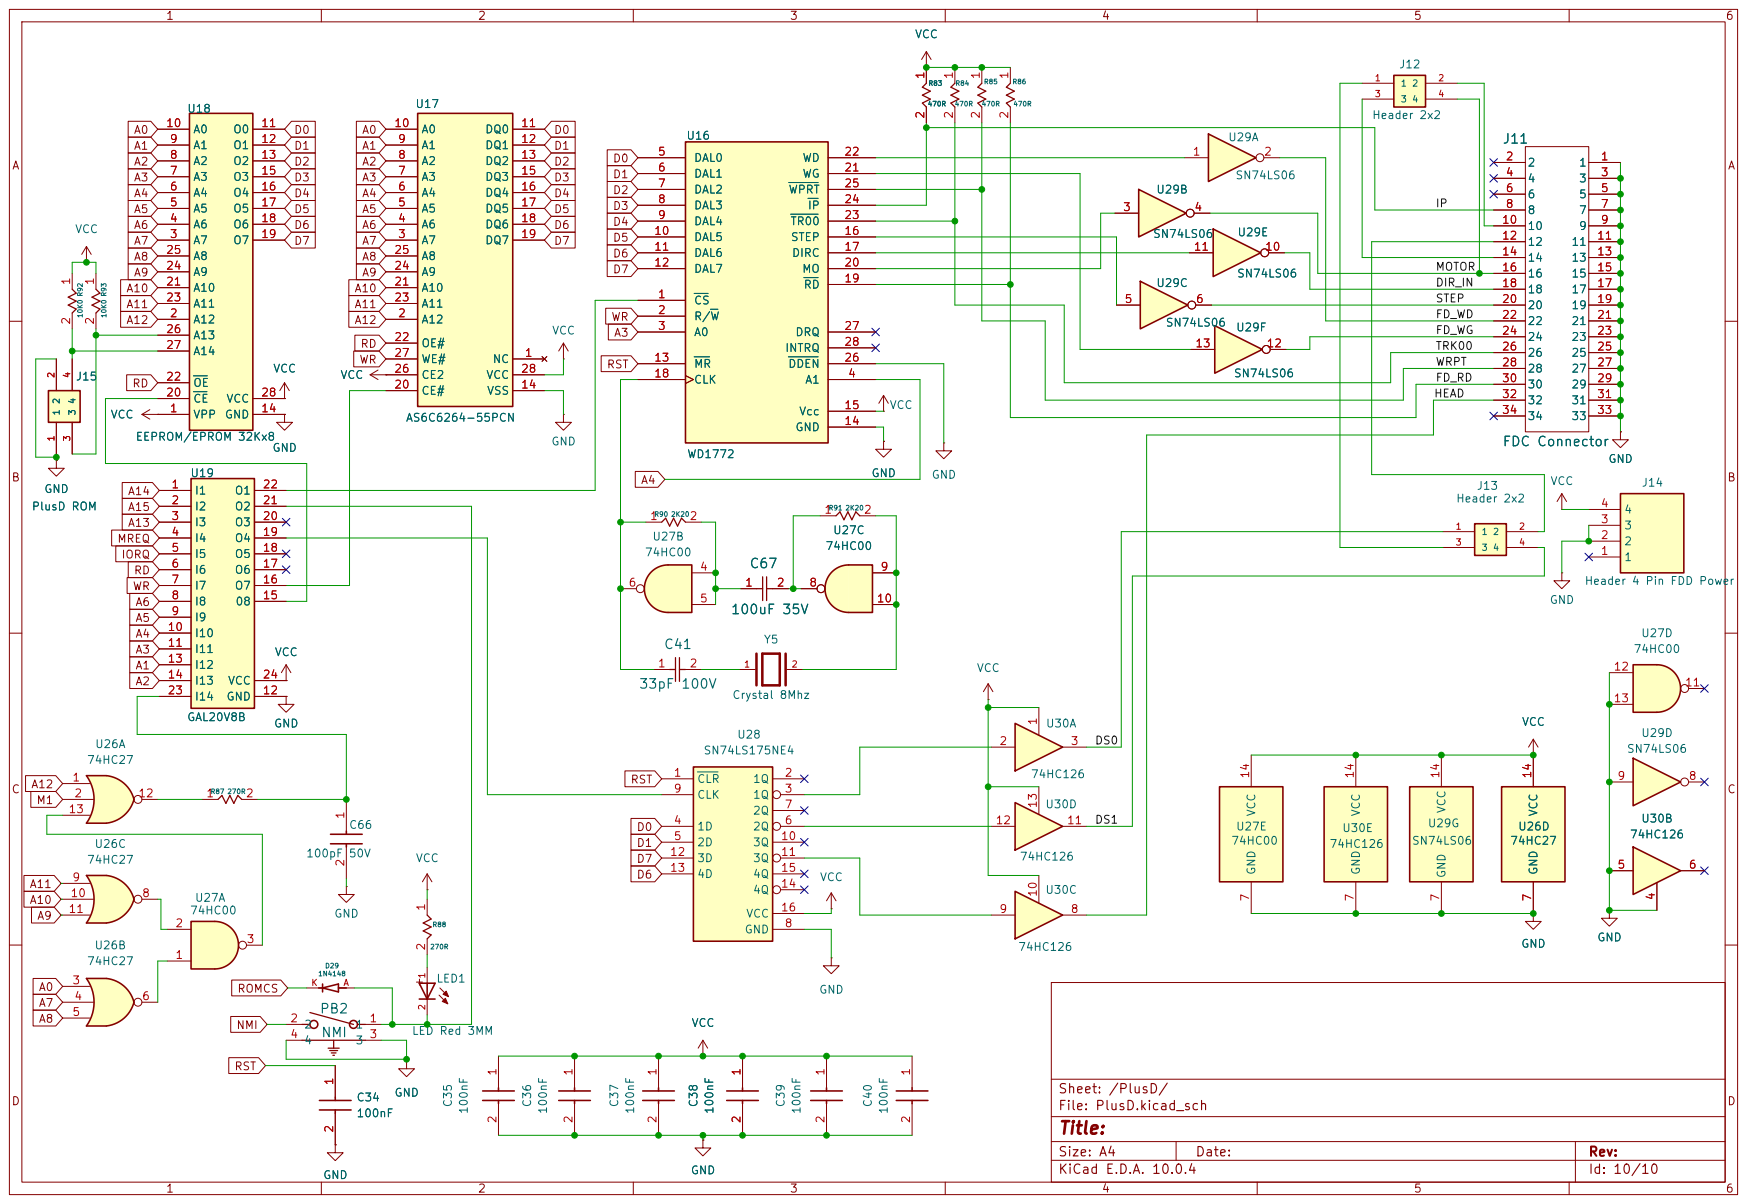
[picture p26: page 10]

J14 Header 4 Pin FDD Power GND

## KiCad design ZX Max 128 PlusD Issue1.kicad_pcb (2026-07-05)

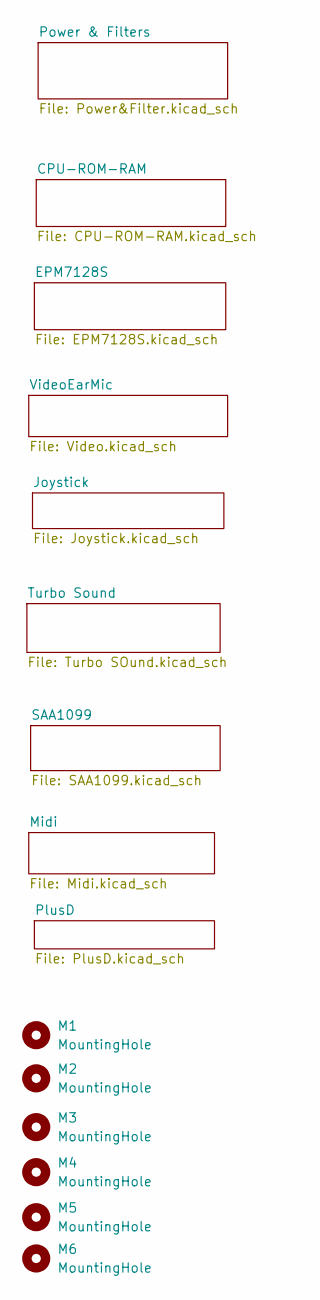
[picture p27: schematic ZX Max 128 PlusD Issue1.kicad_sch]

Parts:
M1, M2, M3, M4, M5, M6: MountingHole; MountingHole_3.2mm_M3_DIN965

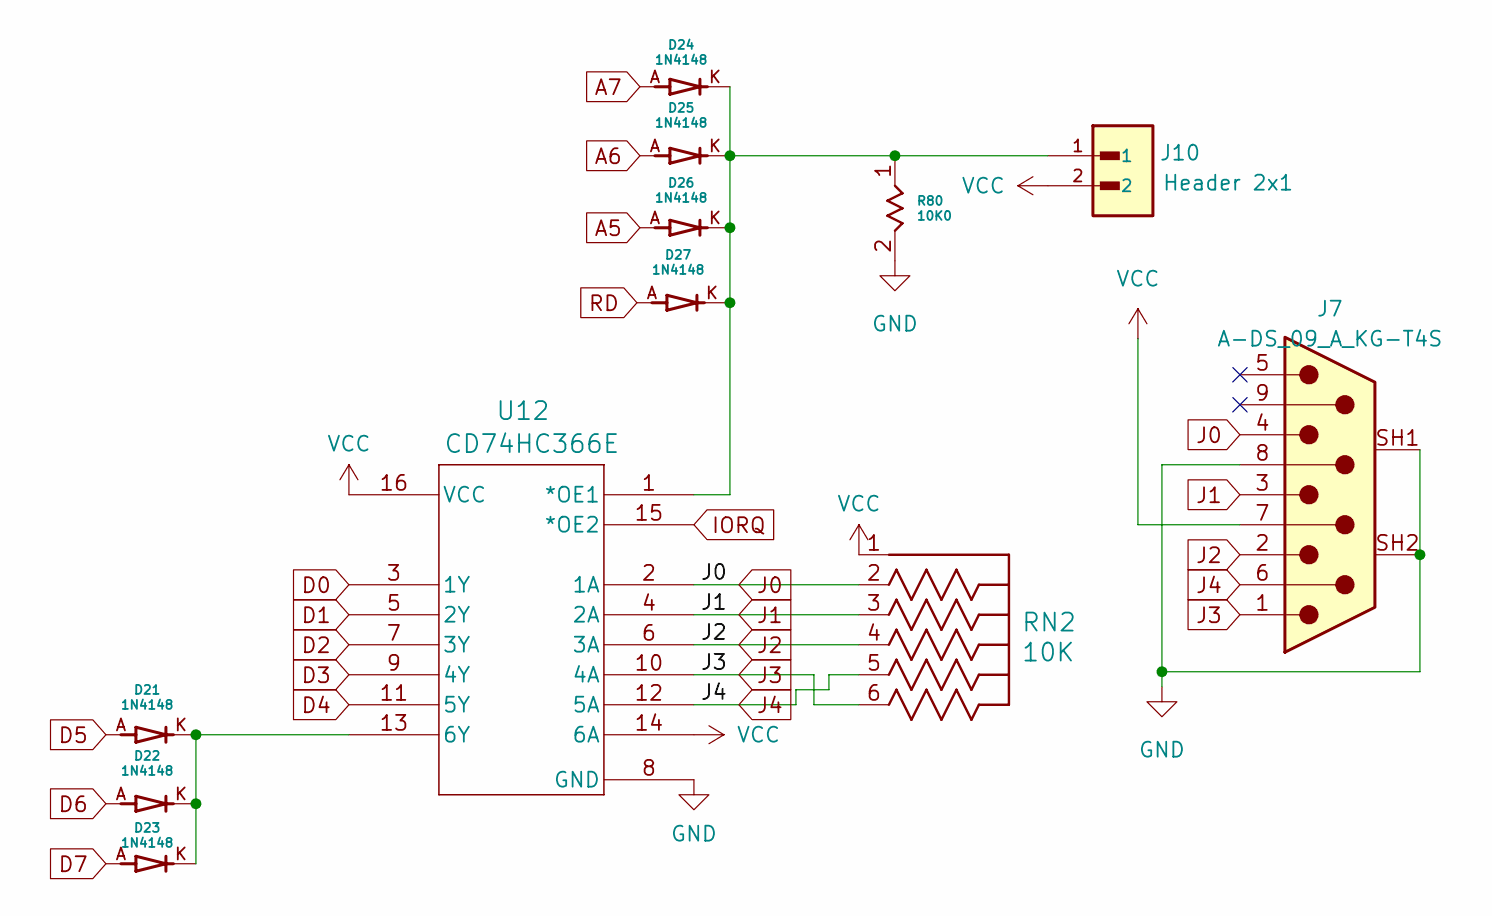
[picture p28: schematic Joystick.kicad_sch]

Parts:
D21, D22, D23, D24, D25, D26, D27: 1N4148; DIOAD753W49L380D172B; PARTREV 5
J7: A-DS_09_A_KG-T4S; ASSMANN_A-DS_09_A_KG-T4S; PARTREV 10
J10: Header 2x1; HARWIN_M20-9990246; PARTREV 14
R80: 10K0; STA_CF14_STP
RN2: 10K; 4606X-101-103LF
U12: CD74HC366E

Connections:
A5: D26.A; also elsewhere on the board
A6: D25.A; also elsewhere on the board
A7: D24.A; also elsewhere on the board
D0: U12.3 (1Y); also elsewhere on the board
D1: U12.5 (2Y); also elsewhere on the board
D2: U12.7 (3Y); also elsewhere on the board
D3: U12.9 (4Y); also elsewhere on the board
D4: U12.11 (5Y); also elsewhere on the board
D5: D21.A; also elsewhere on the board
D6: D22.A; also elsewhere on the board
D7: D23.A; also elsewhere on the board
GND: J7.8, J7.SH1, J7.SH2, R80.2, U12.8 (GND); also elsewhere on the board
IORQ: U12.15 (*OE2); also elsewhere on the board
J0: J7.4, RN2.2, U12.2 (1A)
J1: J7.3, RN2.3, U12.4 (2A)
J2: J7.2, RN2.4, U12.6 (3A)
J3: J7.1, RN2.6, U12.10 (4A)
J4: J7.6, RN2.5, U12.12 (5A)
unnamed: D21.K, D22.K, D23.K, U12.13 (6Y)
unnamed: D24.K, D25.K, D26.K, D27.K, J10.1, R80.1, U12.1 (*OE1)
RD: D27.A; also elsewhere on the board
VCC: J7.7, J10.2, RN2.1, U12.14 (6A), U12.16 (VCC); also elsewhere on the board

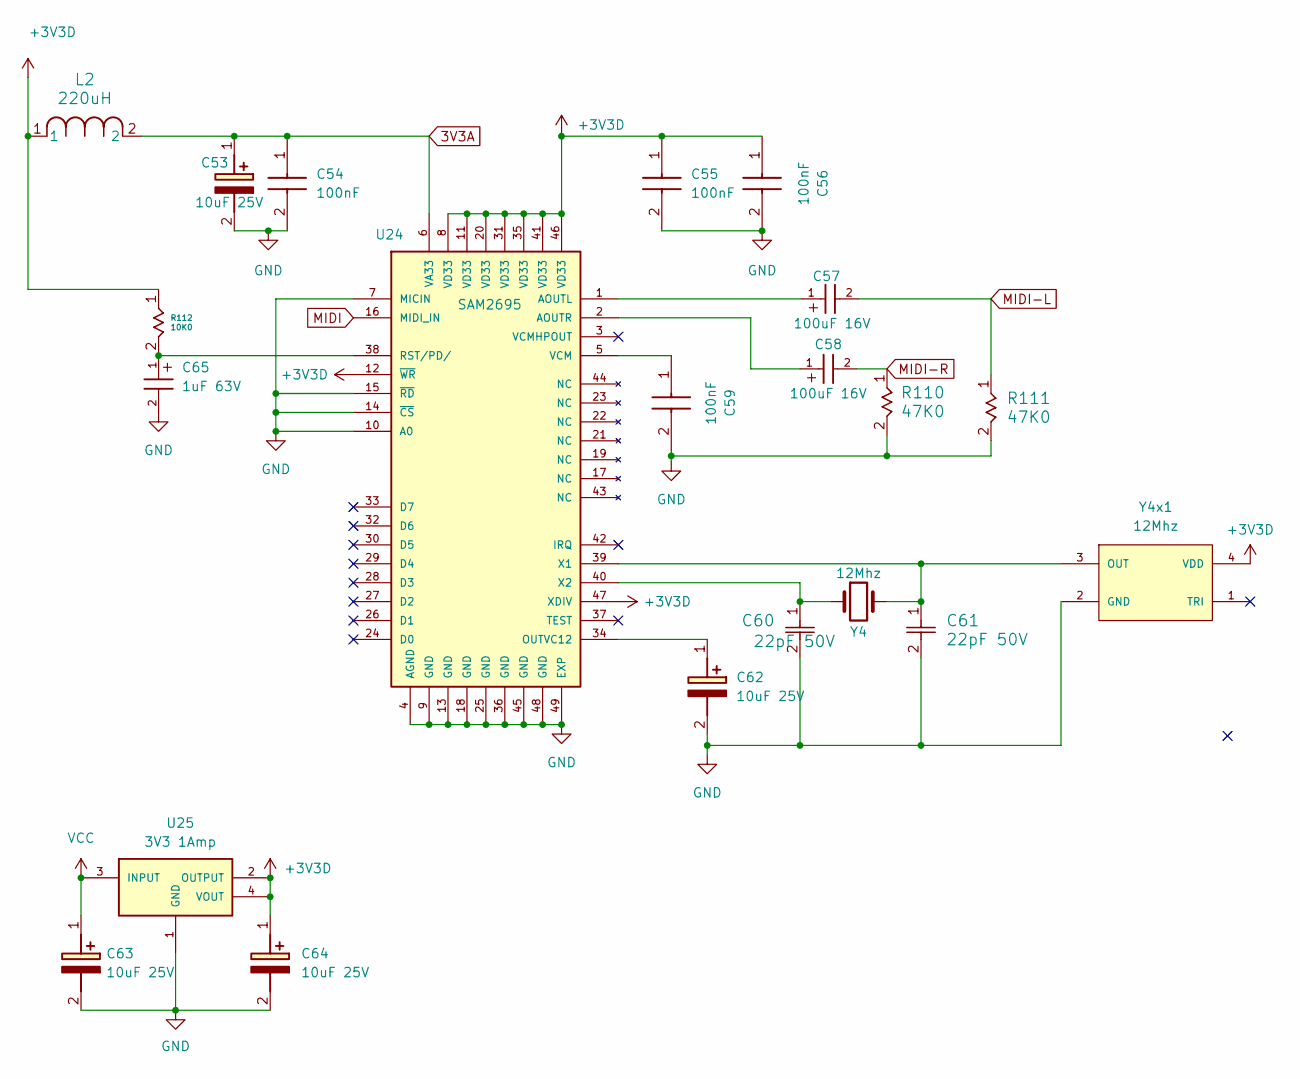
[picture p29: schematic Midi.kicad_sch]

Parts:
C53, C62, C63, C64: 10uF 25V; CAPPRD200W50D500H1100; Mouser Part Number 667-ECA-1EM100B
C54, C55, C56, C59: 100nF; CAPRB250W50L400T250H550; Mouser Part Number 594-K104Z15Y5VF5TL2
C57, C58: 100uF 16V; WCAP-ATG8_5X11_DXL_
C60, C61: 22pF 50V; CAP_K220J15C0GF53L2_VIS
C65: 1uF 63V; WCAP-ATG5_5X11_DXL_
L2: 220uH; IND_BOURNS_RLB0608
R110, R111: 47K0; STA_CF14_STP
R112: 10K0; STA_CF14_STP
U24: SAM2695; QFN40P600X600X90-49N; PARTREV N/A
U25: 3V3 1Amp; SOT230P700X185-4N
Y4: 12Mhz; Crystal_HC49-4H_Vertical
Y4x1: 12Mhz; OSC_ECS-2333-120-BN-TR

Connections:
3V3A: C53.1 (+), C54.1 (+), L2.2, U24.6 (VA33)
+3V3D: C55.1 (+), C56.1 (+), C64.1 (+), L2.1, R112.1, U24.8 (VD33), U24.11 (VD33), U24.12 (~WR), U24.20 (VD33), U24.31 (VD33), U24.35 (VD33), U24.41 (VD33), U24.46 (VD33), U24.47 (XDIV), U25.2 (OUTPUT), U25.4 (VOUT), Y4x1.4 (VDD); also elsewhere on the board
GND: C53.2 (-), C54.2 (-), C55.2 (-), C56.2 (-), C59.2 (-), C60.2, C61.2, C62.2 (-), C63.2 (-), C64.2 (-), C65.2, R110.2, R111.2, U24.4 (AGND), U24.7 (MICIN), U24.9 (GND), U24.10 (A0), U24.13 (GND), U24.14 (~CS), U24.15 (~RD), U24.18 (GND), U24.25 (GND), U24.36 (GND), U24.45 (GND), U24.48 (GND), U24.49 (EXP), U25.1 (GND), Y4x1.2 (GND); also elsewhere on the board
MIDI: U24.16 (MIDI_IN); also elsewhere on the board
MIDI-L: C57.2, R111.1; also elsewhere on the board
MIDI-R: C58.2, R110.1; also elsewhere on the board
unnamed: C59.1 (+), U24.5 (VCM)
unnamed: C62.1 (+), U24.34 (OUTVC12)
unnamed: C57.1, U24.1 (AOUTL)
unnamed: C58.1, U24.2 (AOUTR)
unnamed: C65.1, R112.2, U24.38 (RST/PD/)
unnamed: C61.1, U24.39 (X1), Y4.2, Y4x1.3 (OUT)
unnamed: C60.1, U24.40 (X2), Y4.1
VCC: C63.1 (+), U25.3 (INPUT); also elsewhere on the board

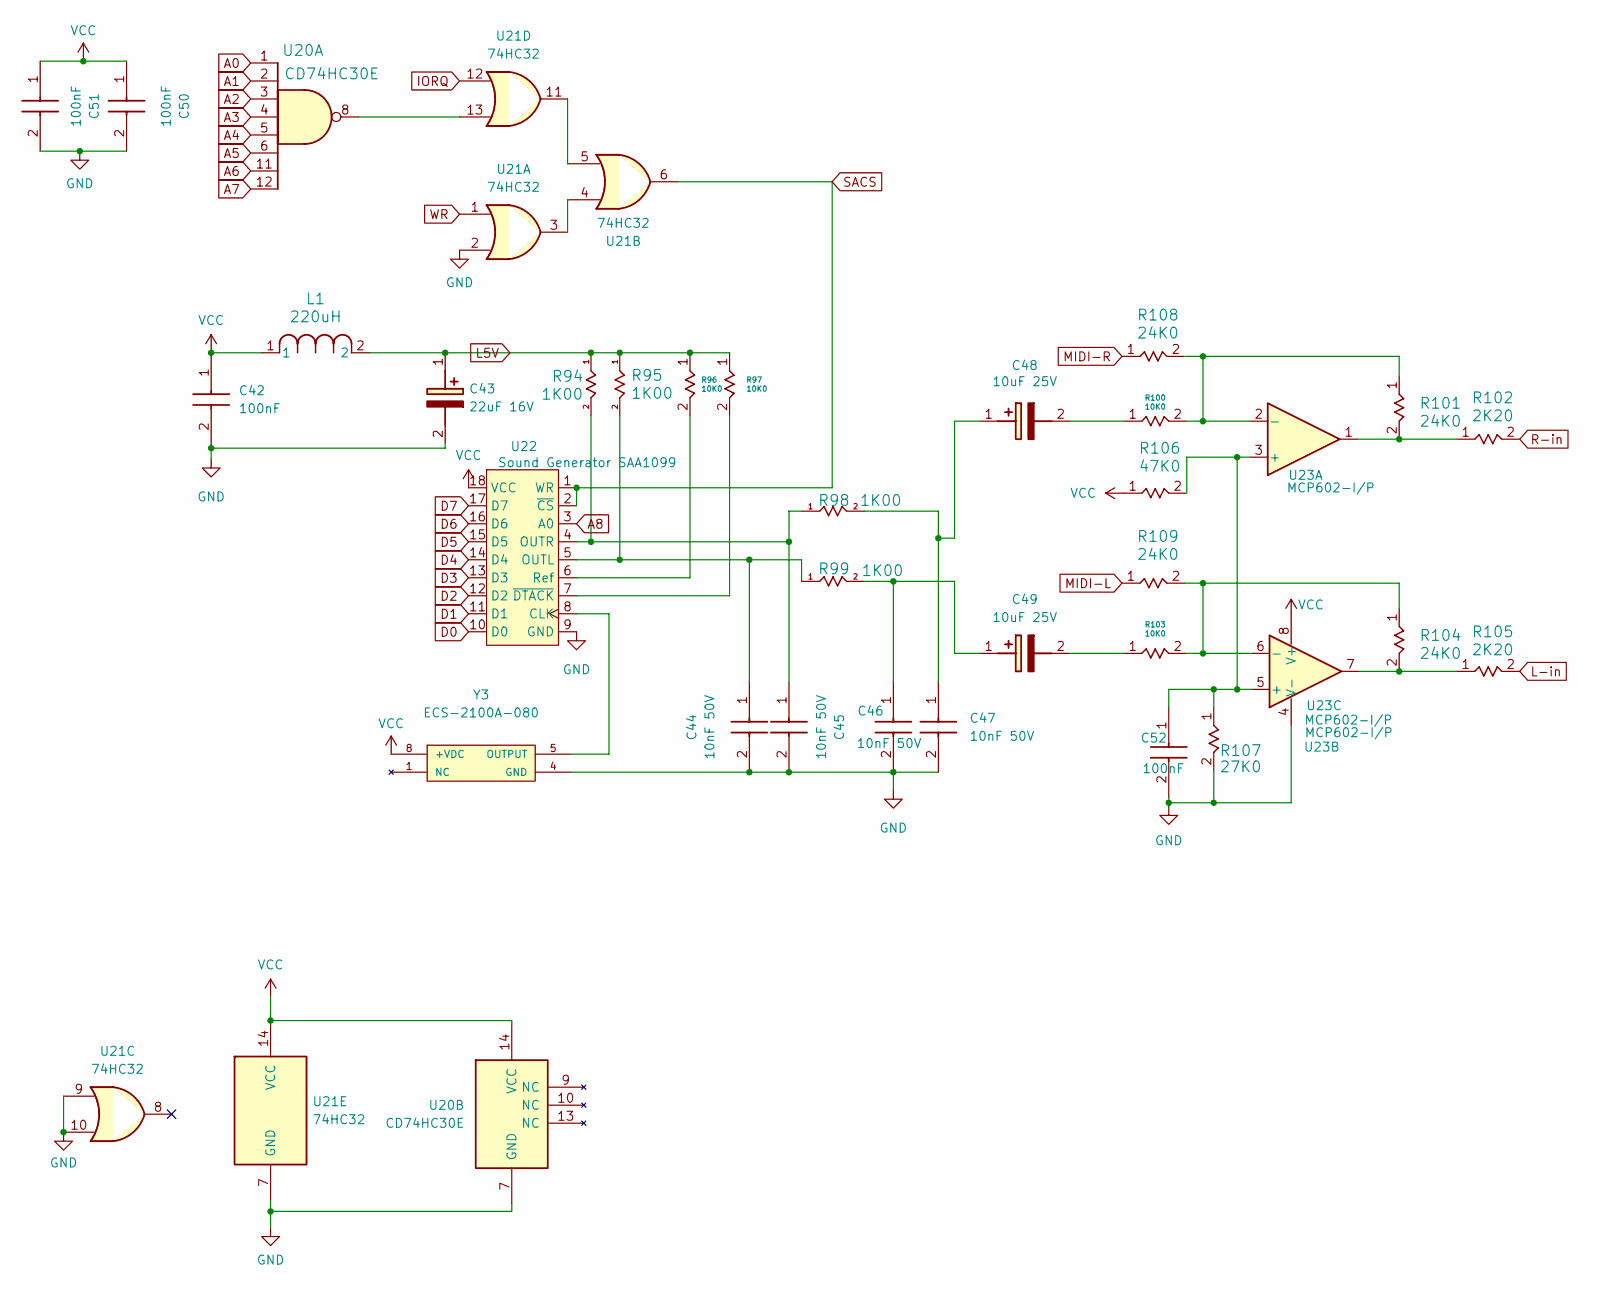
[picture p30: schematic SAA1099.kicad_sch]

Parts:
C42, C50, C51, C52: 100nF; CAPRB250W50L400T250H550; Mouser Part Number 594-K104Z15Y5VF5TL2
C43: 22uF 16V; CAPPRD200W50D500H1100; Mouser Part Number 667-ECA-1EM100B
C44, C45, C46, C47: 10nF 50V; CAPRB250W50L400T250H550; Mouser Part Number 594-K104Z15Y5VF5TL2
C48, C49: 10uF 25V; CAPPRD200W50D500H1100; Mouser Part Number 667-ECA-1EM100B
L1: 220uH; IND_BOURNS_RLB0608
R94, R95, R98, R99: 1K00; STA_CF14_STP
R96, R97, R100, R103: 10K0; STA_CF14_STP
R101, R104, R108, R109: 24K0; STA_CF14_STP
R102, R105: 2K20; STA_CF14_STP
R106: 47K0; STA_CF14_STP
R107: 27K0; STA_CF14_STP
U20: CD74HC30E; DIP794W53P254L1930H508Q14N
U21: 74HC32; DIP794W53P254L1930H508Q14N
U22: Sound Generator SAA1099; DIP-18_W7.62mm_Socket
U23: MCP602-I/P; DIP-8_W7.62mm_Socket
Y3: ECS-2100A-080; OSC_ECS-2100A-080; PARTREV N/A

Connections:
A0: U20.1; also elsewhere on the board
A1: U20.2; also elsewhere on the board
A2: U20.3; also elsewhere on the board
A3: U20.4; also elsewhere on the board
A4: U20.5; also elsewhere on the board
A5: U20.6; also elsewhere on the board
A6: U20.11; also elsewhere on the board
A7: U20.12; also elsewhere on the board
A8: U22.3 (A0); also elsewhere on the board
D0: U22.10 (D0); also elsewhere on the board
D1: U22.11 (D1); also elsewhere on the board
D2: U22.12 (D2); also elsewhere on the board
D3: U22.13 (D3); also elsewhere on the board
D4: U22.14 (D4); also elsewhere on the board
D5: U22.15 (D5); also elsewhere on the board
D6: U22.16 (D6); also elsewhere on the board
D7: U22.17 (D7); also elsewhere on the board
GND: C42.2 (-), C43.2 (-), C44.2 (-), C45.2 (-), C46.2 (-), C47.2 (-), C50.2 (-), C51.2 (-), C52.2 (-), R107.2, U20.7 (GND), U21.2, U21.7 (GND), U21.9, U21.10, U22.9 (GND), U23.4 (V-), Y3.4 (GND); also elsewhere on the board
IORQ: U21.12; also elsewhere on the board
L5V: C43.1 (+), L1.2, R94.1, R95.1, R96.1, R97.1
L-in: R105.2; also elsewhere on the board
MIDI-L: R109.1; also elsewhere on the board
MIDI-R: R108.1; also elsewhere on the board
unnamed: C44.1 (+), R95.2, R99.1, U22.5 (OUTL)
unnamed: C45.1 (+), R94.2, R98.1, U22.4 (OUTR)
unnamed: C46.1 (+), C49.1 (+), R99.2
unnamed: C47.1 (+), C48.1 (+), R98.2
unnamed: C48.2 (-), R100.1
unnamed: C49.2 (-), R103.1
unnamed: C52.1 (+), R106.2, R107.1, U23.3 (+), U23.5 (+)
unnamed: R101.2, R102.1, U23.1
unnamed: R104.2, R105.1, U23.7
unnamed: U20.8, U21.13
unnamed: U21.3, U21.4
unnamed: U21.5, U21.11
unnamed: U22.8 (CLK), Y3.5 (OUTPUT)
unnamed: R96.2, U22.6 (Ref)
unnamed: R97.2, U22.7 (~DTACK)
unnamed: R100.2, R101.1, R108.2, U23.2 (-)
unnamed: R103.2, R104.1, R109.2, U23.6 (-)
R-in: R102.2; also elsewhere on the board
SACS: U21.6, U22.1 (WR), U22.2 (~CS)
VCC: C42.1 (+), C50.1 (+), C51.1 (+), L1.1, R106.1, U20.14 (VCC), U21.14 (VCC), U22.18 (VCC), U23.8 (V+), Y3.8 (+VDC); also elsewhere on the board
WR: U21.1; also elsewhere on the board

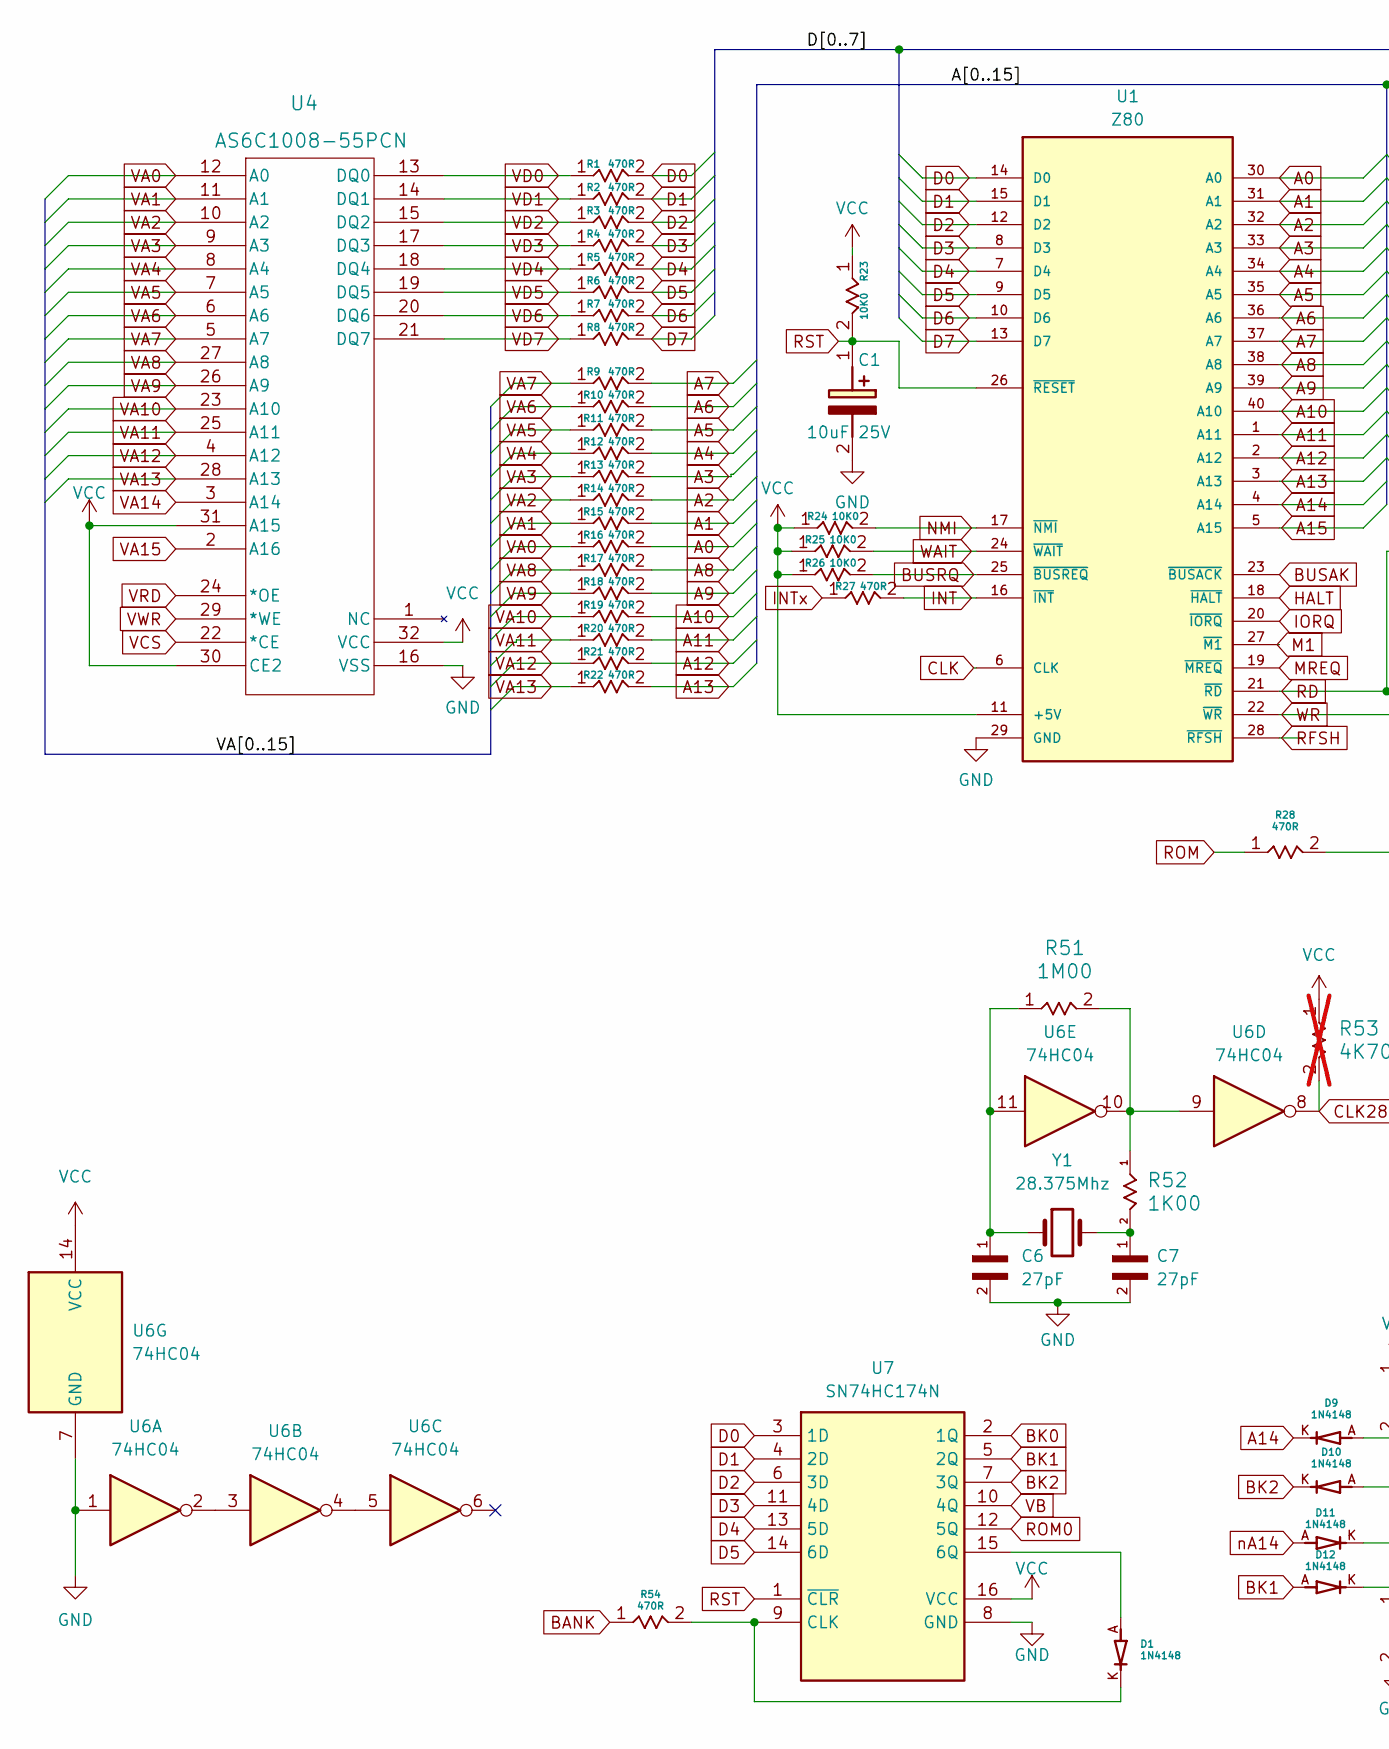
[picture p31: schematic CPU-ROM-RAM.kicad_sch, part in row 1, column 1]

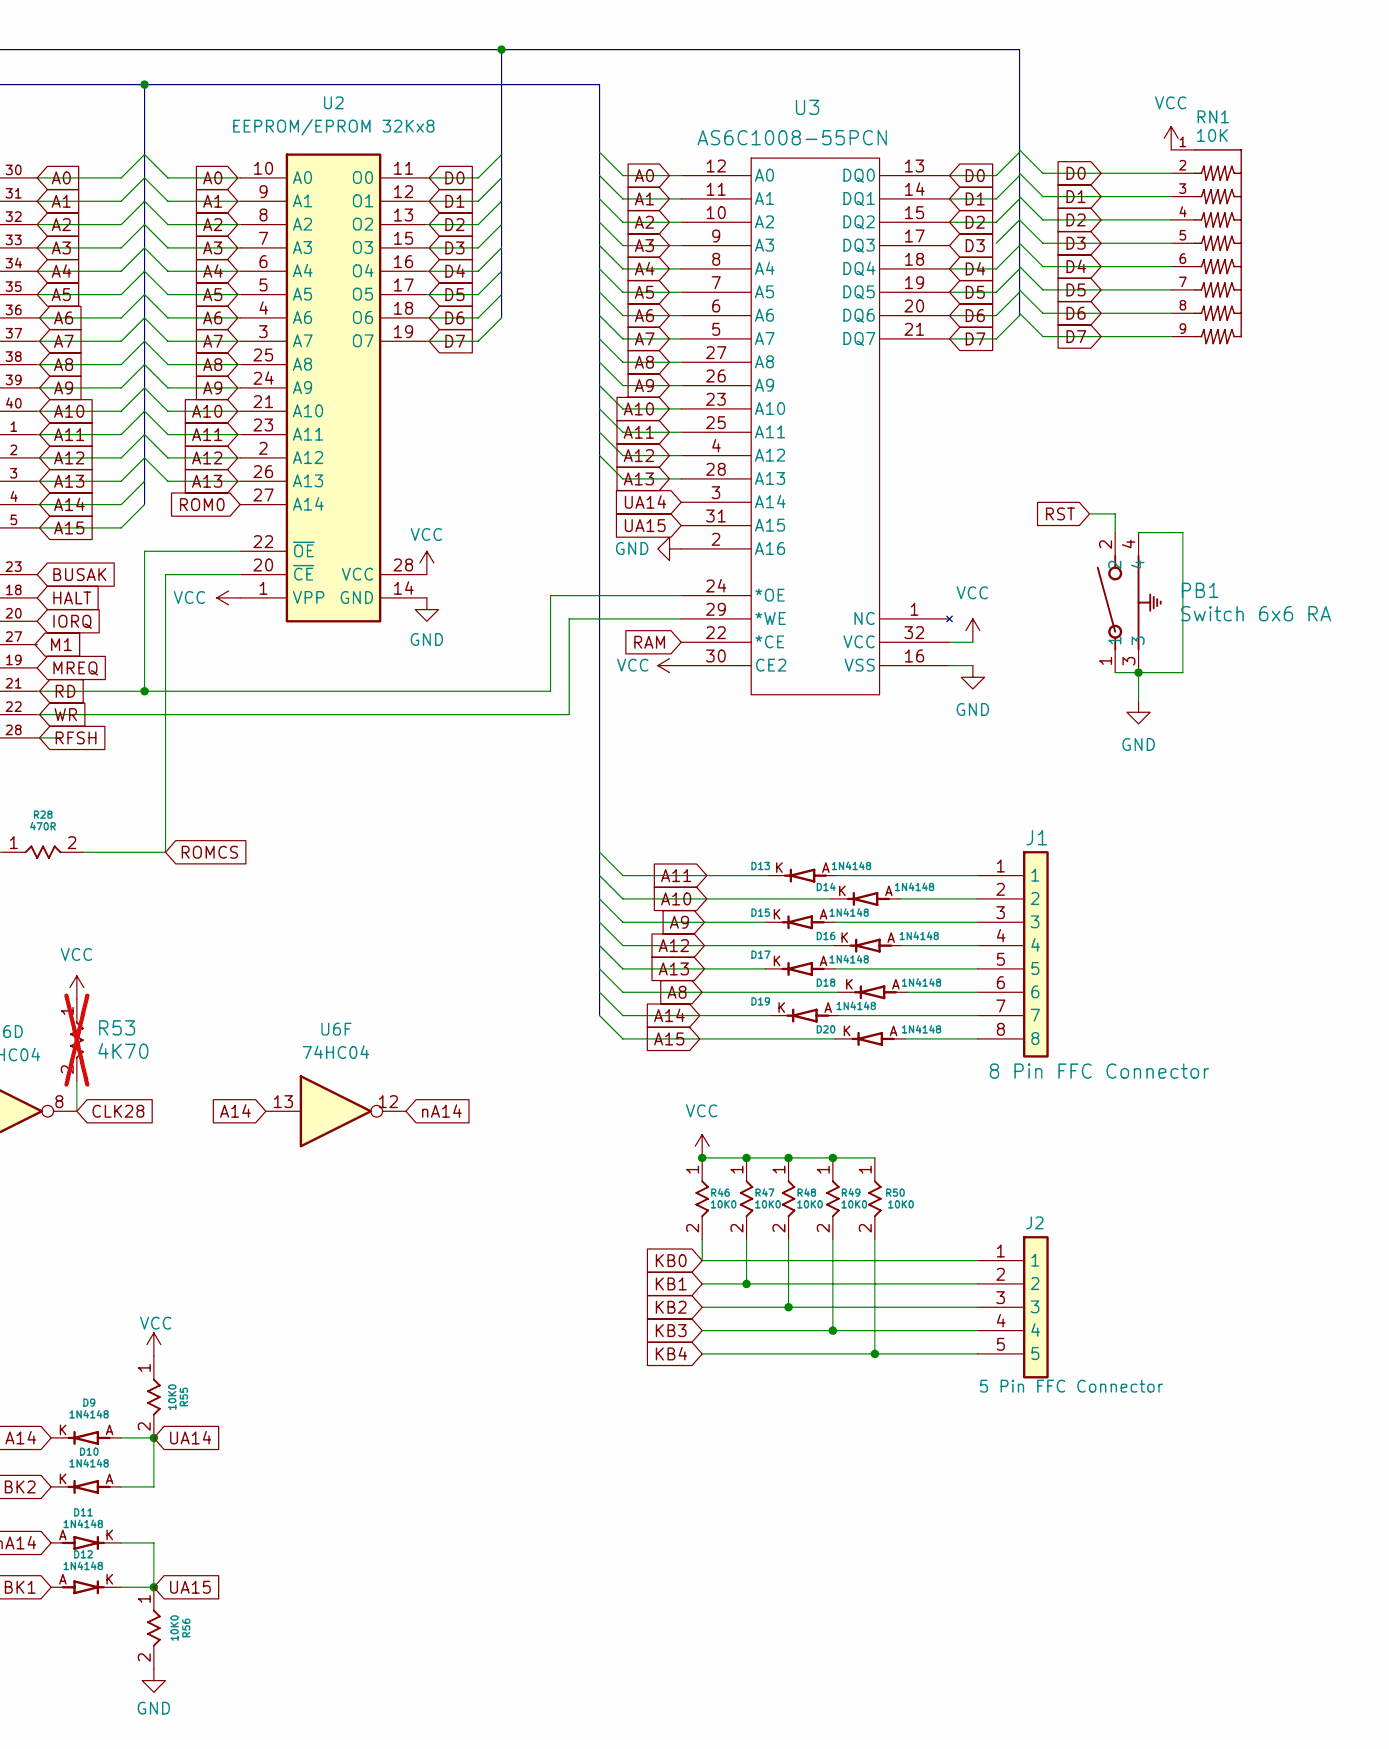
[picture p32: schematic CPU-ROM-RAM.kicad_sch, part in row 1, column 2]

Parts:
C1: 10uF 25V; CAPPRD200W50D500H1100; Mouser Part Number 667-ECA-1EM100B
C6, C7: 27pF; CAPRB250W50L400T250H550; PARTREV 20200310
D1, D9, D10, D11, D12, D13, D14, D15, D16, D17, D18, D19, D20: 1N4148; DIOAD753W49L380D172B; PARTREV 5
J1: 8 Pin FFC Connector; 55203155
J2: 5 Pin FFC Connector; 55203155; Mouser Part Number 571-5-520315-5
PB1: Switch 6x6 RA; SW2_1825027-G_TEC
R1, R2, R3, R4, R5, R6, R7, R8, R9, R10, R11, R12, R13, R14, R15, R16, R17, R18, R19, R20, R21, R22, R27, R28, R54: 470R; STA_CF14_STP
R23, R24, R25, R26, R46, R47, R48, R49, R50, R55, R56: 10K0; STA_CF14_STP
R51: 1M00; STA_CF14_STP
R52: 1K00; STA_CF14_STP
R53: 4K70; STA_CF14_STP; not fitted
RN1: 10K; SIP249W50P254L2281H508Q9; PARTREV 10/1/20
U1: Z80; Z80_Socket
U2: EEPROM/EPROM 32Kx8; DIP1556W56P254L3702H483Q28N; Mouser Part Number 556-AT27C256R-45PU
U3, U4: AS6C1008-55PCN; PDIP-32_MIL600_ALL
U6: 74HC04; DIP794W53P254L1930H508Q14N
U7: SN74HC174N; DIP794W53P254L1930H508Q16N; Mouser Part Number 595-SN74HC174N
Y1: 28.375Mhz; Crystal_HC49-4H_Vertical

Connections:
A0: R16.2, U1.30 (A0), U2.10 (A0), U3.12 (A0); also elsewhere on the board
A1: R15.2, U1.31 (A1), U2.9 (A1), U3.11 (A1); also elsewhere on the board
A2: R14.2, U1.32 (A2), U2.8 (A2), U3.10 (A2); also elsewhere on the board
A3: R13.2, U1.33 (A3), U2.7 (A3), U3.9 (A3); also elsewhere on the board
A4: R12.2, U1.34 (A4), U2.6 (A4), U3.8 (A4); also elsewhere on the board
A5: R11.2, U1.35 (A5), U2.5 (A5), U3.7 (A5); also elsewhere on the board
A6: R10.2, U1.36 (A6), U2.4 (A6), U3.6 (A6); also elsewhere on the board
A7: R9.2, U1.37 (A7), U2.3 (A7), U3.5 (A7); also elsewhere on the board
A8: D18.K, R17.2, U1.38 (A8), U2.25 (A8), U3.27 (A8); also elsewhere on the board
A9: D15.K, R18.2, U1.39 (A9), U2.24 (A9), U3.26 (A9); also elsewhere on the board
A10: D14.K, R19.2, U1.40 (A10), U2.21 (A10), U3.23 (A10); also elsewhere on the board
A11: D13.K, R20.2, U1.1 (A11), U2.23 (A11), U3.25 (A11); also elsewhere on the board
A12: D16.K, R21.2, U1.2 (A12), U2.2 (A12), U3.4 (A12); also elsewhere on the board
A13: D17.K, R22.2, U1.3 (A13), U2.26 (A13), U3.28 (A13); also elsewhere on the board
A14: D9.K, D19.K, U1.4 (A14), U6.13; also elsewhere on the board
A15: D20.K, U1.5 (A15); also elsewhere on the board
BANK: R54.1; also elsewhere on the board
BK0: U7.2 (1Q); also elsewhere on the board
BK1: D12.A, U7.5 (2Q); also elsewhere on the board
BK2: D10.K, U7.7 (3Q); also elsewhere on the board
BUSAK: U1.23 (~BUSACK); also elsewhere on the board
BUSRQ: R26.2, U1.25 (~BUSREQ); also elsewhere on the board
CLK: U1.6 (CLK); also elsewhere on the board
CLK28: R53.2, U6.8; also elsewhere on the board
D0: R1.2, RN1.2, U1.14 (D0), U2.11 (O0), U3.13 (DQ0), U7.3 (1D); also elsewhere on the board
D1: R2.2, RN1.3, U1.15 (D1), U2.12 (O1), U3.14 (DQ1), U7.4 (2D); also elsewhere on the board
D2: R3.2, RN1.4, U1.12 (D2), U2.13 (O2), U3.15 (DQ2), U7.6 (3D); also elsewhere on the board
D3: R4.2, RN1.5, U1.8 (D3), U2.15 (O3), U3.17 (DQ3), U7.11 (4D); also elsewhere on the board
D4: R5.2, RN1.6, U1.7 (D4), U2.16 (O4), U3.18 (DQ4), U7.13 (5D); also elsewhere on the board
D5: R6.2, RN1.7, U1.9 (D5), U2.17 (O5), U3.19 (DQ5), U7.14 (6D); also elsewhere on the board
D6: R7.2, RN1.8, U1.10 (D6), U2.18 (O6), U3.20 (DQ6); also elsewhere on the board
D7: R8.2, RN1.9, U1.13 (D7), U2.19 (O7), U3.21 (DQ7); also elsewhere on the board
GND: C1.2 (-), C6.2, C7.2, PB1.1, PB1.3, PB1.4, R56.2, U1.29 (GND), U2.14 (GND), U3.2 (A16), U3.16 (VSS), U4.16 (VSS), U6.1, U6.7 (GND), U7.8 (GND); also elsewhere on the board
HALT: U1.18 (~HALT); also elsewhere on the board
INT: R27.2, U1.16 (~INT); also elsewhere on the board
INTx: R27.1; also elsewhere on the board
IORQ: U1.20 (~IORQ); also elsewhere on the board
KB0: J2.1, R46.2; also elsewhere on the board
KB1: J2.2, R47.2; also elsewhere on the board
KB2: J2.3, R48.2; also elsewhere on the board
KB3: J2.4, R49.2; also elsewhere on the board
KB4: J2.5, R50.2; also elsewhere on the board
M1: U1.27 (~M1); also elsewhere on the board
MREQ: U1.19 (~MREQ); also elsewhere on the board
NMI: R24.2, U1.17 (~NMI); also elsewhere on the board
unnamed: C6.1, R51.1, U6.11, Y1.1
unnamed: C7.1, R52.2, Y1.2
unnamed: D13.A, J1.1
unnamed: D14.A, J1.2
unnamed: D15.A, J1.3
unnamed: D16.A, J1.4
unnamed: D17.A, J1.5
unnamed: D18.A, J1.6
unnamed: D19.A, J1.7
unnamed: D20.A, J1.8
unnamed: R51.2, R52.1, U6.9, U6.10
unnamed: U6.2, U6.3
unnamed: U6.4, U6.5
unnamed: D1.A, U7.15 (6Q)
unnamed: D1.K, R54.2, U7.9 (CLK)
RAM: U3.22 (*CE); also elsewhere on the board
RD: U1.21 (~RD), U2.22 (~OE), U3.24 (*OE); also elsewhere on the board
RFSH: U1.28 (~RFSH); also elsewhere on the board
ROM: R28.1; also elsewhere on the board
ROM0: U2.27 (A14), U7.12 (5Q)
ROMCS: R28.2, U2.20 (~CE); also elsewhere on the board
RST: C1.1 (+), PB1.2, R23.2, U1.26 (~RESET), U7.1 (~CLR); also elsewhere on the board
UA14: D9.A, D10.A, R55.2, U3.3 (A14)
UA15: D11.K, D12.K, R56.1, U3.31 (A15)
VA0: R16.1, U4.12 (A0); also elsewhere on the board
VA1: R15.1, U4.11 (A1); also elsewhere on the board
VA2: R14.1, U4.10 (A2); also elsewhere on the board
VA3: R13.1, U4.9 (A3); also elsewhere on the board
VA4: R12.1, U4.8 (A4); also elsewhere on the board
VA5: R11.1, U4.7 (A5); also elsewhere on the board
VA6: R10.1, U4.6 (A6); also elsewhere on the board
VA7: R9.1, U4.5 (A7); also elsewhere on the board
VA8: R17.1, U4.27 (A8); also elsewhere on the board
VA9: R18.1, U4.26 (A9); also elsewhere on the board
VA10: R19.1, U4.23 (A10); also elsewhere on the board
VA11: R20.1, U4.25 (A11); also elsewhere on the board
VA12: R21.1, U4.4 (A12); also elsewhere on the board
VA13: R22.1, U4.28 (A13); also elsewhere on the board
VA14: U4.3 (A14); also elsewhere on the board
VA15: U4.2 (A16); also elsewhere on the board
VB: U7.10 (4Q); also elsewhere on the board
VCC: R23.1, R24.1, R25.1, R26.1, R46.1, R47.1, R48.1, R49.1, R50.1, R53.1, R55.1, RN1.1, U1.11 (+5V), U2.1 (VPP), U2.28 (VCC), U3.30 (CE2), U3.32 (VCC), U4.30 (CE2), U4.31 (A15), U4.32 (VCC), U6.14 (VCC), U7.16 (VCC); also elsewhere on the board
VCS: U4.22 (*CE); also elsewhere on the board
VD0: R1.1, U4.13 (DQ0); also elsewhere on the board
VD1: R2.1, U4.14 (DQ1); also elsewhere on the board
VD2: R3.1, U4.15 (DQ2); also elsewhere on the board
VD3: R4.1, U4.17 (DQ3); also elsewhere on the board
VD4: R5.1, U4.18 (DQ4); also elsewhere on the board
VD5: R6.1, U4.19 (DQ5); also elsewhere on the board
VD6: R7.1, U4.20 (DQ6); also elsewhere on the board
VD7: R8.1, U4.21 (DQ7); also elsewhere on the board
VRD: U4.24 (*OE); also elsewhere on the board
VWR: U4.29 (*WE); also elsewhere on the board
WAIT: R25.2, U1.24 (~WAIT); also elsewhere on the board
WR: U1.22 (~WR), U3.29 (*WE); also elsewhere on the board
nA14: D11.A, U6.12

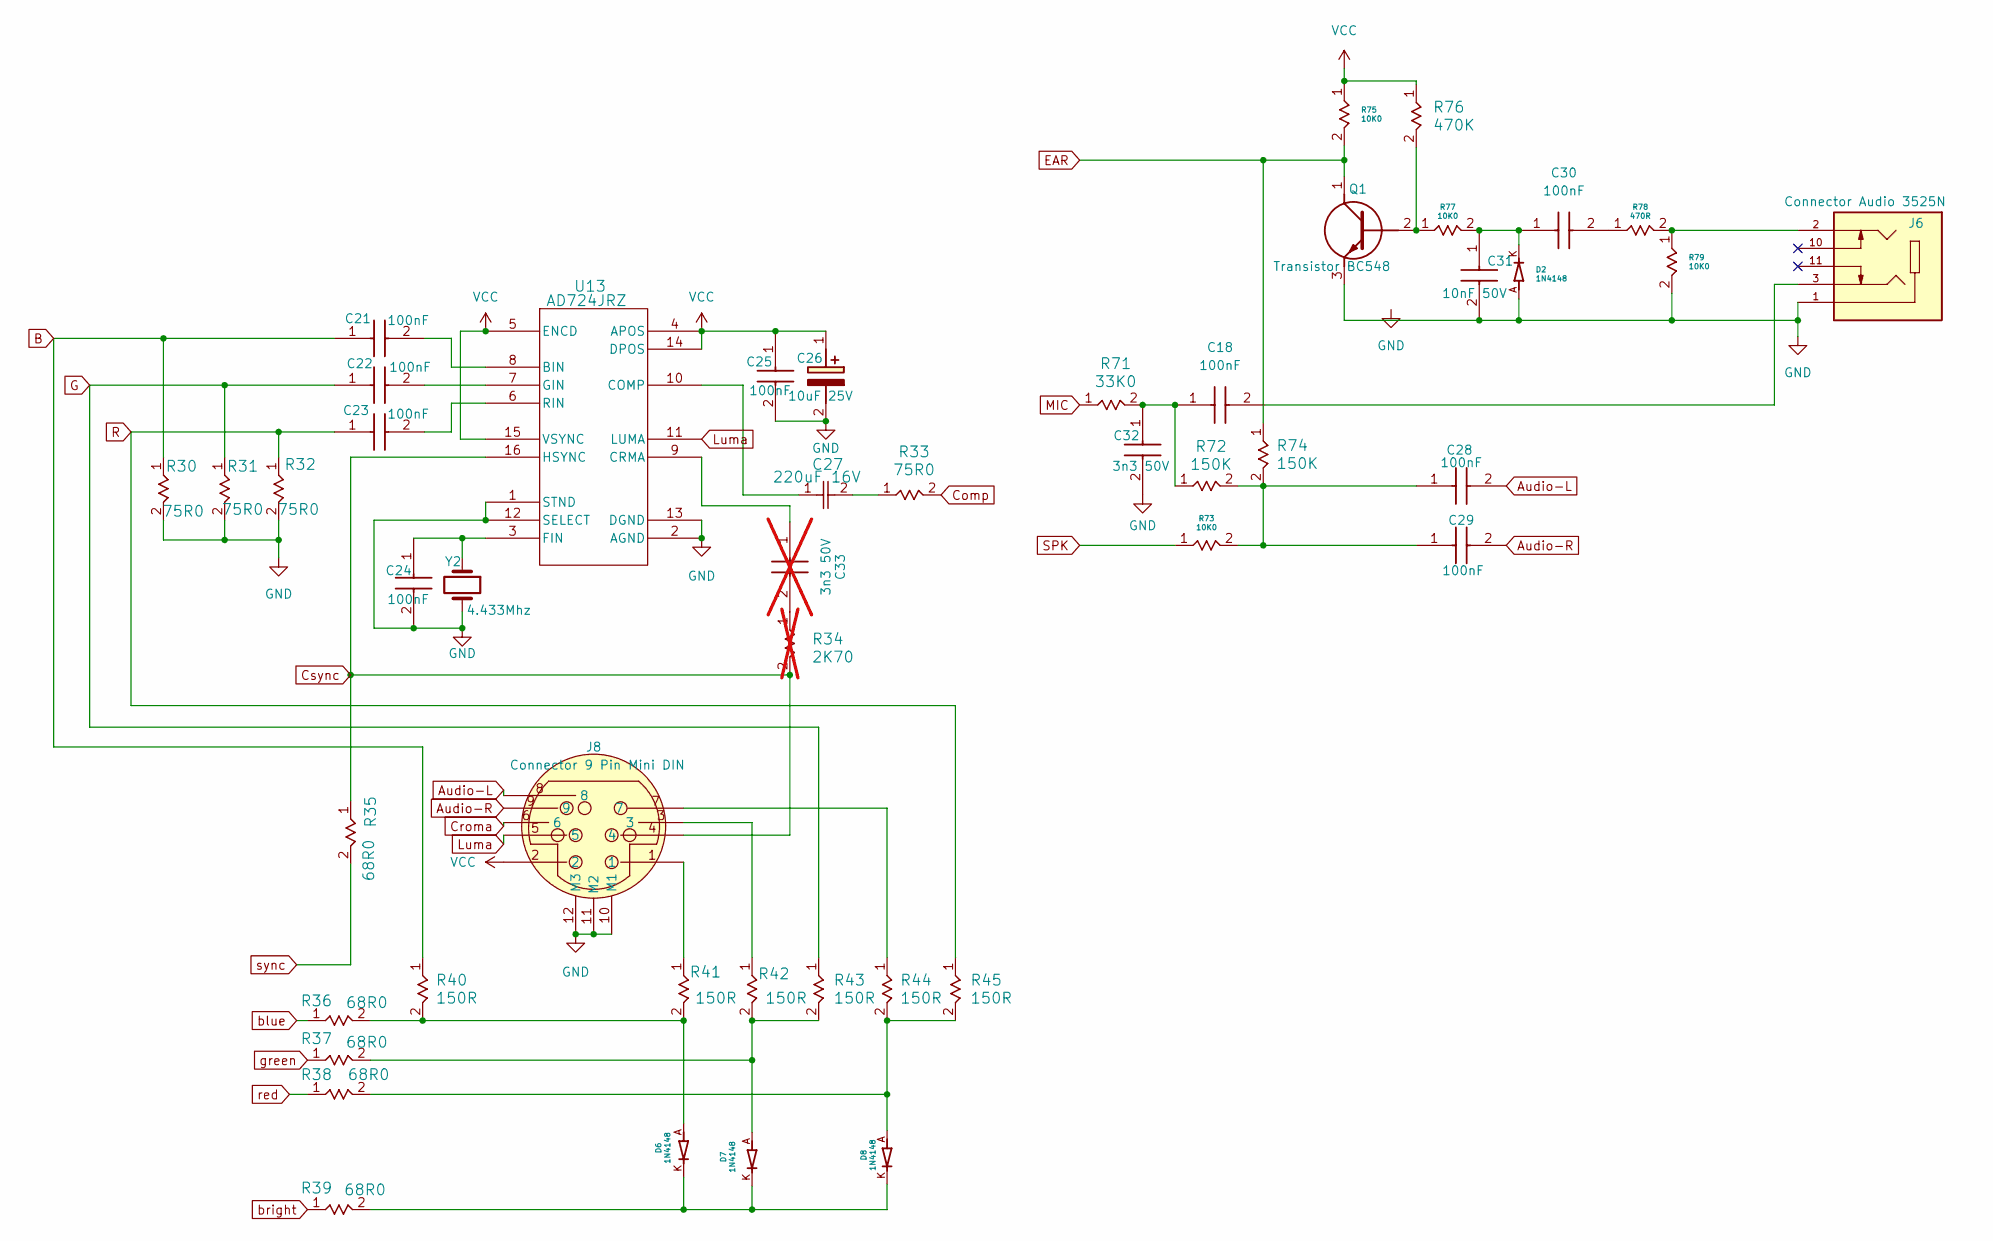
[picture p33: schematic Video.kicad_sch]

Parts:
C18, C21, C22, C23, C24, C25, C28, C29, C30: 100nF; CAPRB250W50L400T250H550; Mouser Part Number 594-K104Z15Y5VF5TL2
C26: 10uF 25V; CAPPRD200W50D500H1100; Mouser Part Number 667-ECA-1EM100B
C27: 220uF 16V; CAPPRD200W50D500H1100
C31: 10nF 50V; CAPRB250W50L400T250H550; Mouser Part Number 594-K104Z15Y5VF5TL2
C32: 3n3 50V; CAPRB250W50L400T250H550; Mouser Part Number 594-K104Z15Y5VF5TL2
C33: 3n3 50V; CAPRB250W50L400T250H550; Mouser Part Number 594-K104Z15Y5VF5TL2; not fitted
D2, D6, D7, D8: 1N4148; DIOAD753W49L380D172B; PARTREV 5
J6: Connector Audio 3525N; CUI_SJ1-3525N
J8: Connector 9 Pin Mini DIN; KMDGX9SBS1; Mouser Part Number 806-KMDGX-9S-BS-1
Q1: Transistor BC548; BC548BTA
R30, R31, R32, R33: 75R0; STA_CF14_STP
R34: 2K70; STA_CF14_STP; not fitted
R35, R36, R37, R38, R39: 68R0; STA_CF14_STP
R40, R41, R42, R43, R44, R45: 150R; STA_CF14_STP
R71: 33K0; STA_CF14_STP
R72, R74: 150K; STA_CF14_STP
R73, R75, R77, R79: 10K0; STA_CF14_STP
R76: 470K; STA_CF14_STP
R78: 470R; STA_CF14_STP
U13: AD724JRZ; RW_16_ADI
Y2: 4.433Mhz; Crystal_HC49-4H_Vertical

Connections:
Audio-L: C28.2 (-), J8.8; also elsewhere on the board
Audio-R: C29.2 (-), J8.9; also elsewhere on the board
B: C21.1 (+), R30.1, R40.1
Comp: R33.2; also elsewhere on the board
Croma: J8.6
Csync: J8.4, R34.2, R35.1, U13.16 (HSYNC)
EAR: Q1.1 (C), R74.1, R75.2; also elsewhere on the board
G: C22.1 (+), R31.1, R43.1
GND: C24.2 (-), C25.2 (-), C26.2 (-), C31.2 (-), C32.2 (-), D2.A, J6.1, J8.10 (MH1), J8.11 (MH2), J8.12 (MH3), Q1.3 (E), R30.2, R31.2, R32.2, R79.2, U13.1 (STND), U13.2 (AGND), U13.12 (SELECT), U13.13 (DGND), Y2.2; also elsewhere on the board
Luma: J8.5, U13.11 (LUMA)
MIC: R71.1; also elsewhere on the board
unnamed: C18.1 (+), C32.1 (+), R71.2, R72.1
unnamed: C18.2 (-), J6.3
unnamed: C21.2 (-), U13.8 (BIN)
unnamed: C22.2 (-), U13.7 (GIN)
unnamed: C23.2 (-), U13.6 (RIN)
unnamed: C24.1 (+), U13.3 (FIN), Y2.1
unnamed: C27.2, R33.1
unnamed: C28.1 (+), C29.1 (+), R72.2, R73.2, R74.2
unnamed: C30.1 (+), C31.1 (+), D2.K, R77.2
unnamed: C30.2 (-), R78.1
unnamed: C33.1 (+), U13.9 (CRMA)
unnamed: C33.2 (-), R34.1
unnamed: D6.A, R36.2, R40.2, R41.2
unnamed: D6.K, D7.K, D8.K, R39.2
unnamed: D7.A, R37.2, R42.2, R43.2
unnamed: D8.A, R38.2, R44.2, R45.2
unnamed: J6.2, R78.2, R79.1
unnamed: J8.1, R41.1
unnamed: J8.3, R42.1
unnamed: J8.7, R44.1
unnamed: Q1.2 (B), R76.2, R77.1
unnamed: C27.1, U13.10 (COMP)
R: C23.1 (+), R32.1, R45.1
SPK: R73.1; also elsewhere on the board
VCC: C25.1 (+), C26.1 (+), J8.2, R75.1, R76.1, U13.4 (APOS), U13.5 (ENCD), U13.14 (DPOS), U13.15 (VSYNC); also elsewhere on the board
blue: R36.1; also elsewhere on the board
bright: R39.1; also elsewhere on the board
green: R37.1; also elsewhere on the board
red: R38.1; also elsewhere on the board
sync: R35.2; also elsewhere on the board

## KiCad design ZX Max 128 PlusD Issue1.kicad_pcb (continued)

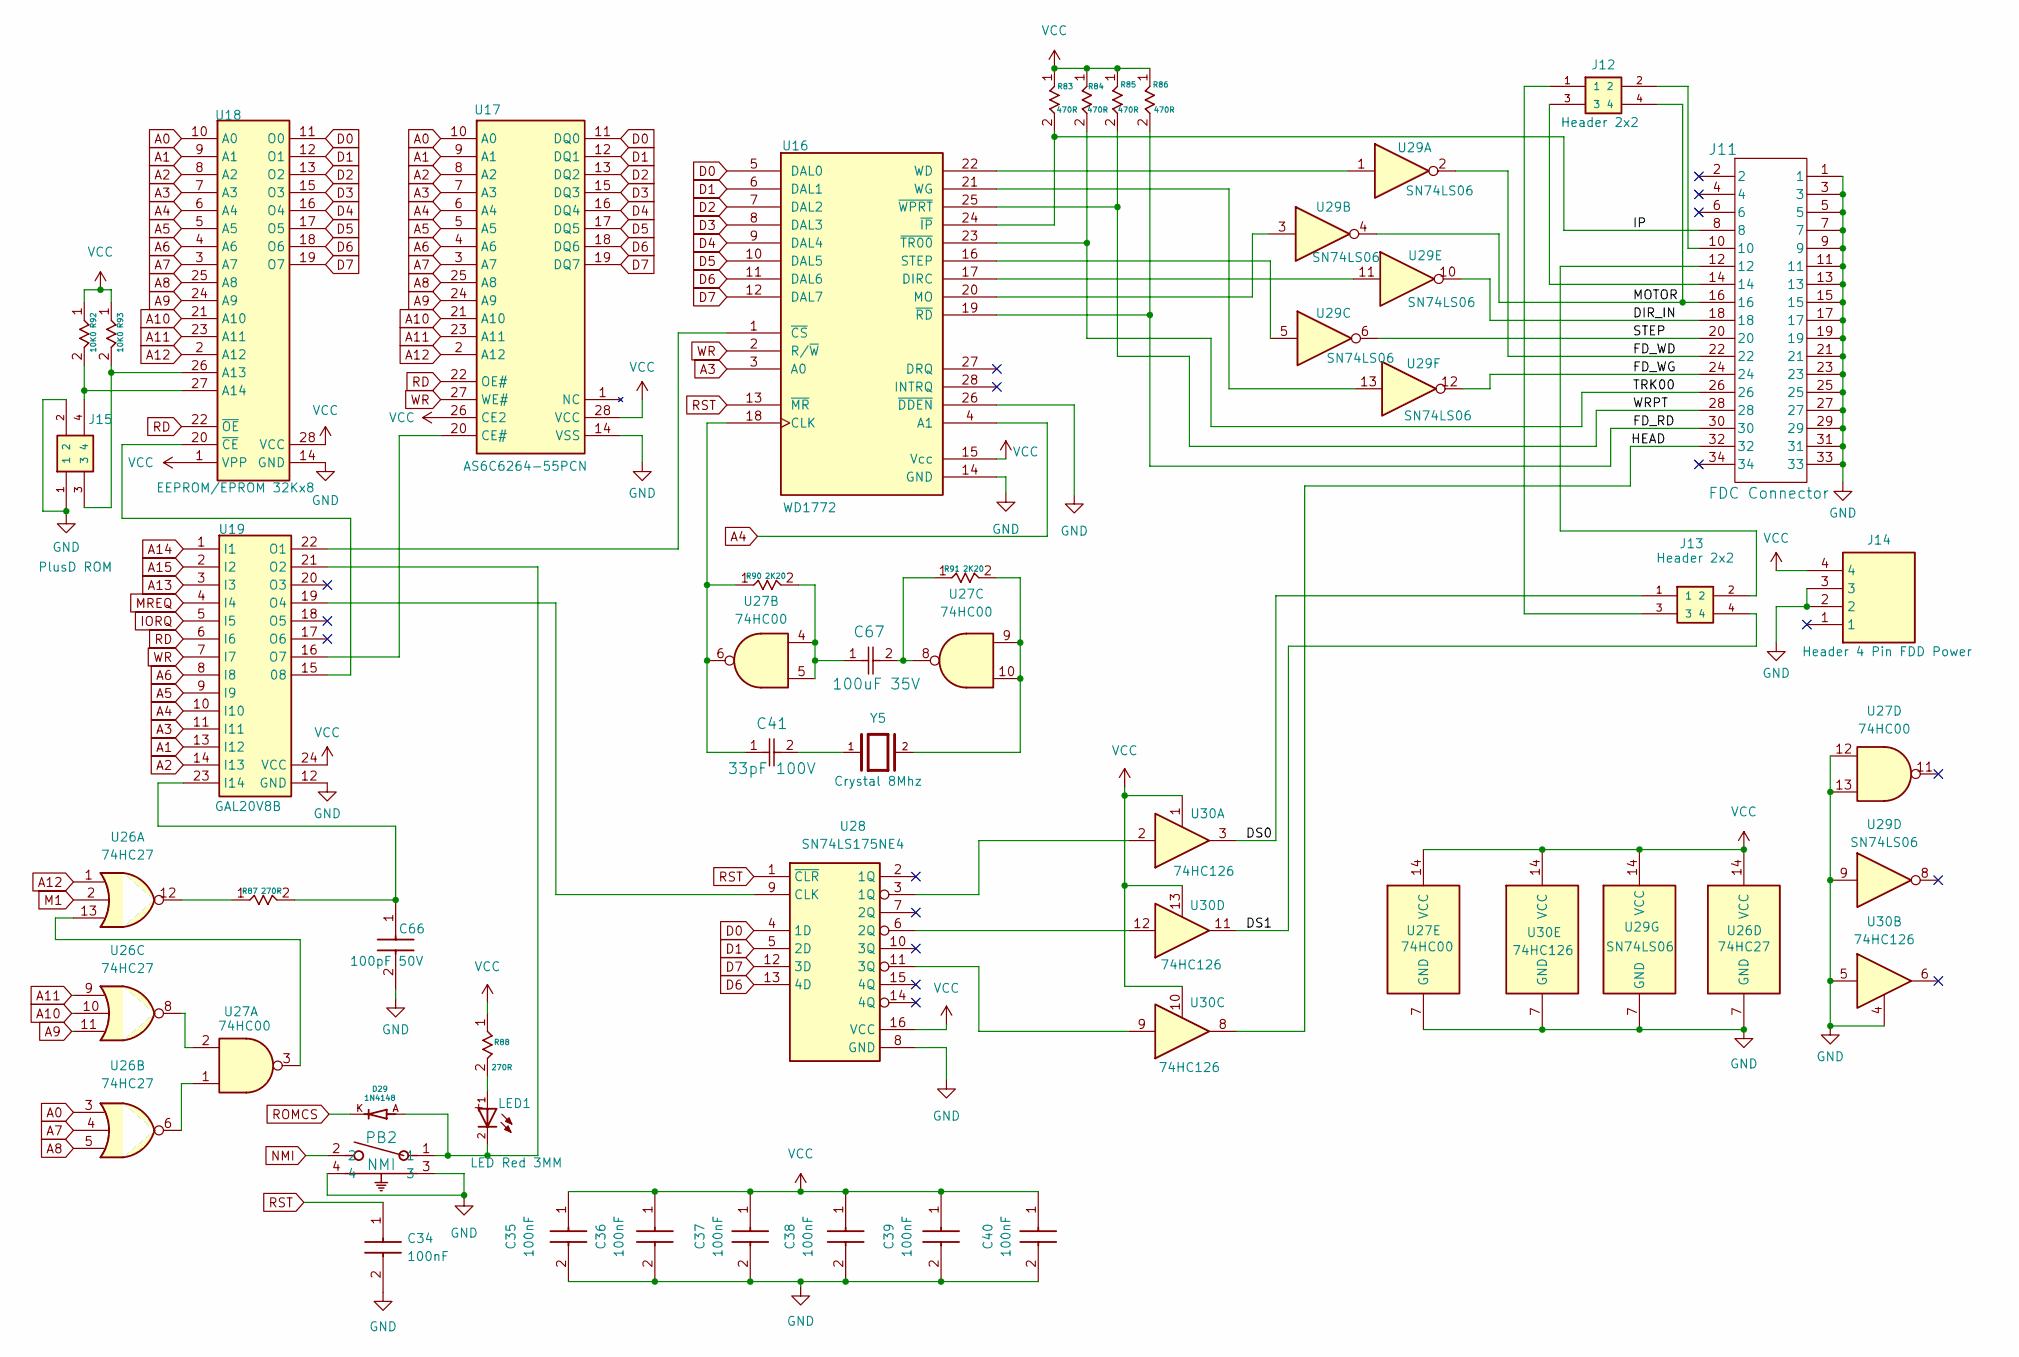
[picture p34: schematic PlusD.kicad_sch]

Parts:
C34, C35, C36, C37, C38, C39, C40: 100nF; CAPRB250W50L400T250H550; Mouser Part Number 594-K104Z15Y5VF5TL2
C41: 33pF 100V; K101J15C0GF53L2
C66: 100pF 50V; K101J15C0GF53L2
C67: 100uF 35V; CAP_YX_6P3X11_RUB
D29: 1N4148; DIOAD753W49L380D172B
J11: FDC Connector; CONN_5103311-7_TYC
J12, J13: Header 2x2; ADAM_PH2-04-UA
J14: Header 4 Pin FDD Power; HDRRA4W64P0X254_1X4_1016X320X610P
J15: PlusD ROM; ADAM_PH2-04-UA
LED1: LED Red 3MM; WL-TMRC_3MM
PB2: NMI; SW2_1825027-G_TEC
R83, R84, R85, R86: 470R; STA_CF14_STP
R87, R88: 270R; STA_CF14_STP
R90, R91: 2K20; STA_CF14_STP
R92, R93: 10K0; STA_CF14_STP
U16: WD1772; DIP1555W45P254L3733H482Q28
U17: AS6C6264-55PCN; DIP1555W45P254L3733H482Q28
U18: EEPROM/EPROM 32Kx8; DIP1556W56P254L3702H483Q28N
U19: GAL20V8B; DIP-24_W7.62mm_Socket
U26: 74HC27; DIP794W53P254L1930H508Q14N
U27: 74HC00; DIP794W53P254L1930H508Q14N
U28: SN74LS175NE4; DIP794W53P254L1930H508Q16N; Mouser Part Number 595-SN74LS175NE4
U29: SN74LS06; DIP794W53P254L1930H508Q14N
U30: 74HC126; DIP794W53P254L1930H508Q14N
Y5: Crystal 8Mhz; XTAL_HC49P488W43L1085T450H368

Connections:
/PlusD/DIR_IN: J11.18, U29.10
/PlusD/DS0: J13.1, U30.3
/PlusD/DS1: J13.4, U30.11
/PlusD/FD_RD: J11.30, R86.2, U16.19 (~RD)
/PlusD/FD_WD: J11.22, U29.2
/PlusD/FD_WG: J11.24, U29.12
/PlusD/HEAD: J11.32, U30.8
/PlusD/IP: J11.8, R83.2, U16.24 (~IP)
/PlusD/MOTOR: J11.16, J12.4, U29.4
/PlusD/STEP: J11.20, U29.6
/PlusD/TRK00: J11.26, R84.2, U16.23 (~TR00)
/PlusD/WRPT: J11.28, R85.2, U16.25 (~WPRT)
A0: U17.10 (A0), U18.10 (A0), U26.3; also elsewhere on the board
A1: U17.9 (A1), U18.9 (A1), U19.13 (I12); also elsewhere on the board
A2: U17.8 (A2), U18.8 (A2), U19.14 (I13); also elsewhere on the board
A3: U16.3 (A0), U17.7 (A3), U18.7 (A3), U19.11 (I11); also elsewhere on the board
A4: U16.4 (A1), U17.6 (A4), U18.6 (A4), U19.10 (I10); also elsewhere on the board
A5: U17.5 (A5), U18.5 (A5), U19.9 (I9); also elsewhere on the board
A6: U17.4 (A6), U18.4 (A6), U19.8 (I8); also elsewhere on the board
A7: U17.3 (A7), U18.3 (A7), U26.4; also elsewhere on the board
A8: U17.25 (A8), U18.25 (A8), U26.5; also elsewhere on the board
A9: U17.24 (A9), U18.24 (A9), U26.11; also elsewhere on the board
A10: U17.21 (A10), U18.21 (A10), U26.10; also elsewhere on the board
A11: U17.23 (A11), U18.23 (A11), U26.9; also elsewhere on the board
A12: U17.2 (A12), U18.2 (A12), U26.1; also elsewhere on the board
A13: U19.3 (I3); also elsewhere on the board
A14: U19.1 (I1); also elsewhere on the board
A15: U19.2 (I2); also elsewhere on the board
D0: U16.5 (DAL0), U17.11 (DQ0), U18.11 (O0), U28.4 (1D); also elsewhere on the board
D1: U16.6 (DAL1), U17.12 (DQ1), U18.12 (O1), U28.5 (2D); also elsewhere on the board
D2: U16.7 (DAL2), U17.13 (DQ2), U18.13 (O2); also elsewhere on the board
D3: U16.8 (DAL3), U17.15 (DQ3), U18.15 (O3); also elsewhere on the board
D4: U16.9 (DAL4), U17.16 (DQ4), U18.16 (O4); also elsewhere on the board
D5: U16.10 (DAL5), U17.17 (DQ5), U18.17 (O5); also elsewhere on the board
D6: U16.11 (DAL6), U17.18 (DQ6), U18.18 (O6), U28.13 (4D); also elsewhere on the board
D7: U16.12 (DAL7), U17.19 (DQ7), U18.19 (O7), U28.12 (3D); also elsewhere on the board
GND: C34.2 (-), C35.2 (-), C36.2 (-), C37.2 (-), C38.2 (-), C39.2 (-), C40.2 (-), C66.2, J11.1, J11.3, J11.5, J11.7, J11.9, J11.11, J11.13, J11.15, J11.17, J11.19, J11.21, J11.23, J11.25, J11.27, J11.29, J11.31, J11.33, J14.2, J14.3, J15.1, J15.2, PB2.3, PB2.4, U16.14 (GND), U16.26 (~DDEN), U17.14 (VSS), U18.14 (GND), U19.12 (GND), U26.7 (GND), U27.7 (GND), U27.12, U27.13, U28.8 (GND), U29.7 (GND), U29.9, U30.4, U30.5, U30.7 (GND); also elsewhere on the board
IORQ: U19.5 (I5); also elsewhere on the board
M1: U26.2; also elsewhere on the board
MREQ: U19.4 (I4); also elsewhere on the board
NMI: PB2.2; also elsewhere on the board
unnamed: C41.2, Y5.1
unnamed: C67.1, R90.2, U27.4, U27.5
unnamed: C67.2, R91.1, U27.8
unnamed: J11.10, J12.2
unnamed: J11.12, J13.2
unnamed: J11.14, J12.3
unnamed: J12.1, J13.3
unnamed: LED1.1, R88.2
unnamed: R87.1, U26.12
unnamed: R91.2, U27.9, U27.10, Y5.2
unnamed: C41.1, R90.1, U16.18 (CLK), U27.6
unnamed: U16.17 (DIRC), U29.11
unnamed: U16.20 (MO), U29.3
unnamed: U16.16 (STEP), U29.5
unnamed: U16.22 (WD), U29.1
unnamed: U16.21 (WG), U29.13
unnamed: U16.1 (~CS), U19.22 (O1)
unnamed: U17.20 (CE#), U19.16 (O7)
unnamed: J15.3, R93.2, U18.26 (A13)
unnamed: J15.4, R92.2, U18.27 (A14)
unnamed: U18.20 (~CE), U19.15 (08)
unnamed: C66.1, R87.2, U19.23 (I14)
unnamed: D29.A, LED1.2, PB2.1, U19.21 (O2)
unnamed: U19.19 (O4), U28.9 (CLK)
unnamed: U26.6, U27.1
unnamed: U26.8, U27.2
unnamed: U26.13, U27.3
unnamed: U28.3 (1Q), U30.2
unnamed: U28.6 (2Q), U30.12
unnamed: U28.11 (3Q), U30.9
RD: U17.22 (OE#), U18.22 (~OE), U19.6 (I6); also elsewhere on the board
ROMCS: D29.K; also elsewhere on the board
RST: C34.1 (+), U16.13 (~MR), U28.1 (~CLR); also elsewhere on the board
VCC: C35.1 (+), C36.1 (+), C37.1 (+), C38.1 (+), C39.1 (+), C40.1 (+), J14.4, R83.1, R84.1, R85.1, R86.1, R88.1, R92.1, R93.1, U16.15 (Vcc), U17.26 (CE2), U17.28 (VCC), U18.1 (VPP), U18.28 (VCC), U19.24 (VCC), U26.14 (VCC), U27.14 (VCC), U28.16 (VCC), U29.14 (VCC), U30.1, U30.10, U30.13, U30.14 (VCC); also elsewhere on the board
WR: U16.2 (R/~W), U17.27 (WE#), U19.7 (I7); also elsewhere on the board

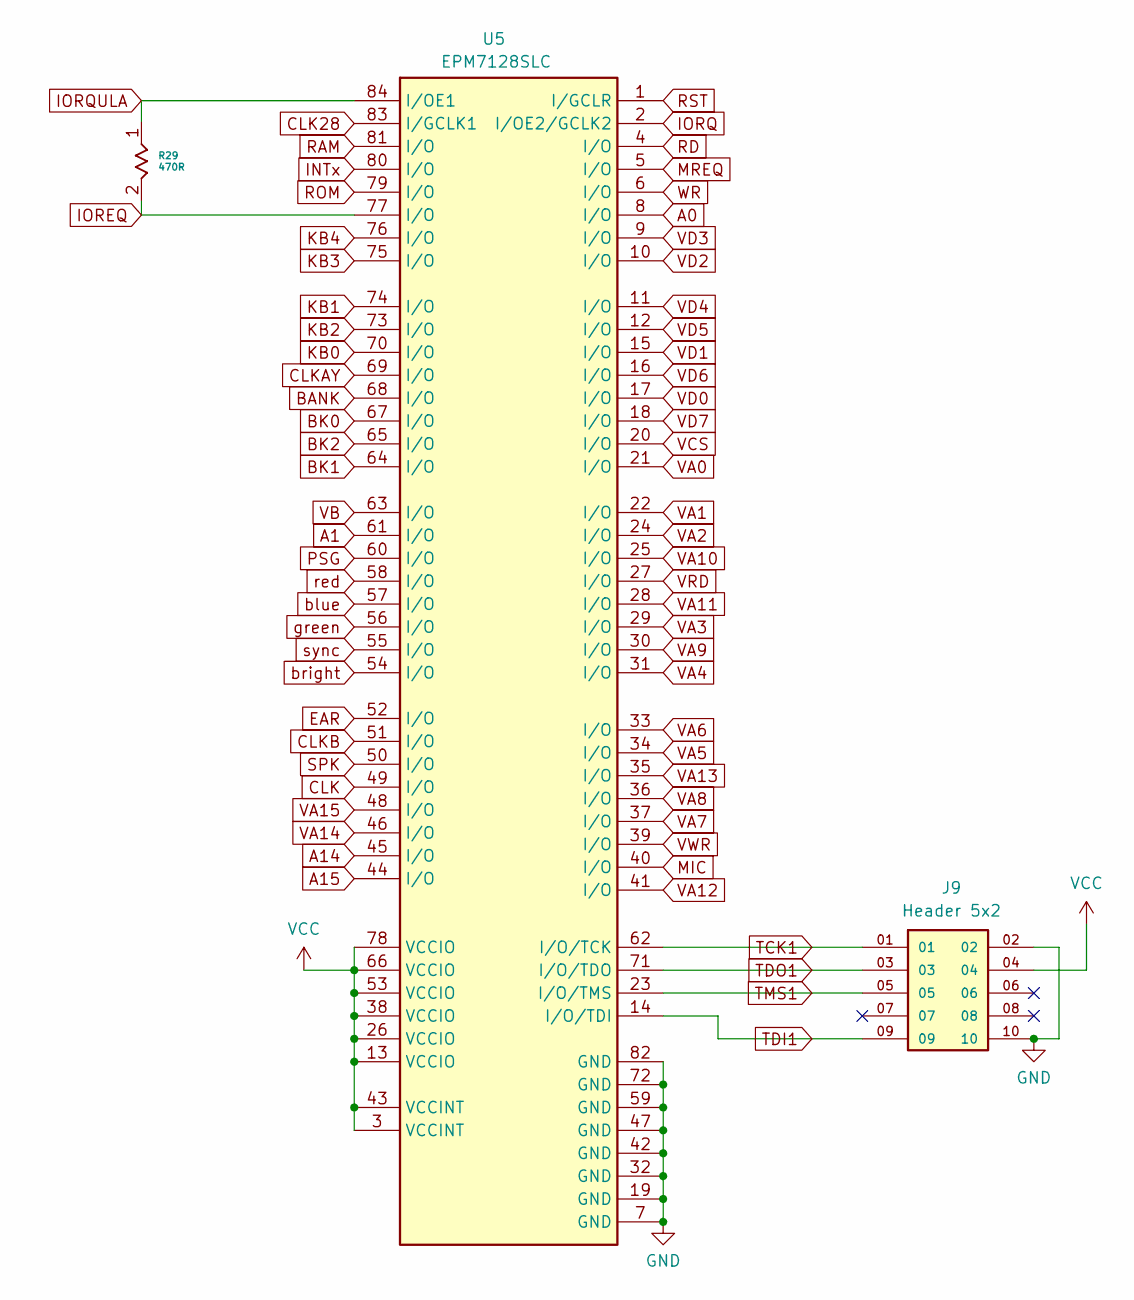
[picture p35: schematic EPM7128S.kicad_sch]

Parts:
J9: Header 5x2; AMPHENOL_10129381-910002BLF; PARTREV D
R29: 470R; STA_CF14_STP
U5: EPM7128SLC; PLCC84AT

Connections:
A0: U5.8 (I/O); also elsewhere on the board
A1: U5.61 (I/O); also elsewhere on the board
A14: U5.45 (I/O); also elsewhere on the board
A15: U5.44 (I/O); also elsewhere on the board
BANK: U5.68 (I/O); also elsewhere on the board
BK0: U5.67 (I/O); also elsewhere on the board
BK1: U5.64 (I/O); also elsewhere on the board
BK2: U5.65 (I/O); also elsewhere on the board
CLK: U5.49 (I/O); also elsewhere on the board
CLK28: U5.83 (I/GCLK1); also elsewhere on the board
CLKAY: U5.69 (I/O); also elsewhere on the board
CLKB: U5.51 (I/O); also elsewhere on the board
EAR: U5.52 (I/O); also elsewhere on the board
GND: J9.02, J9.10, U5.7 (GND), U5.19 (GND), U5.32 (GND), U5.42 (GND), U5.47 (GND), U5.59 (GND), U5.72 (GND), U5.82 (GND); also elsewhere on the board
INTx: U5.80 (I/O); also elsewhere on the board
IOREQ: R29.2, U5.77 (I/O)
IORQ: U5.2 (I/OE2/GCLK2); also elsewhere on the board
IORQULA: R29.1, U5.84 (I/OE1); also elsewhere on the board
KB0: U5.70 (I/O); also elsewhere on the board
KB1: U5.74 (I/O); also elsewhere on the board
KB2: U5.73 (I/O); also elsewhere on the board
KB3: U5.75 (I/O); also elsewhere on the board
KB4: U5.76 (I/O); also elsewhere on the board
MIC: U5.40 (I/O); also elsewhere on the board
MREQ: U5.5 (I/O); also elsewhere on the board
PSG: U5.60 (I/O); also elsewhere on the board
RAM: U5.81 (I/O); also elsewhere on the board
RD: U5.4 (I/O); also elsewhere on the board
ROM: U5.79 (I/O); also elsewhere on the board
RST: U5.1 (I/GCLR); also elsewhere on the board
SPK: U5.50 (I/O); also elsewhere on the board
TCK1: J9.01, U5.62 (I/O/TCK)
TDI1: J9.09, U5.14 (I/O/TDI)
TDO1: J9.03, U5.71 (I/O/TDO)
TMS1: J9.05, U5.23 (I/O/TMS)
VA0: U5.21 (I/O); also elsewhere on the board
VA1: U5.22 (I/O); also elsewhere on the board
VA2: U5.24 (I/O); also elsewhere on the board
VA3: U5.29 (I/O); also elsewhere on the board
VA4: U5.31 (I/O); also elsewhere on the board
VA5: U5.34 (I/O); also elsewhere on the board
VA6: U5.33 (I/O); also elsewhere on the board
VA7: U5.37 (I/O); also elsewhere on the board
VA8: U5.36 (I/O); also elsewhere on the board
VA9: U5.30 (I/O); also elsewhere on the board
VA10: U5.25 (I/O); also elsewhere on the board
VA11: U5.28 (I/O); also elsewhere on the board
VA12: U5.41 (I/O); also elsewhere on the board
VA13: U5.35 (I/O); also elsewhere on the board
VA14: U5.46 (I/O); also elsewhere on the board
VA15: U5.48 (I/O); also elsewhere on the board
VB: U5.63 (I/O); also elsewhere on the board
VCC: J9.04, U5.3 (VCCINT), U5.13 (VCCIO), U5.26 (VCCIO), U5.38 (VCCIO), U5.43 (VCCINT), U5.53 (VCCIO), U5.66 (VCCIO), U5.78 (VCCIO); also elsewhere on the board
VCS: U5.20 (I/O); also elsewhere on the board
VD0: U5.17 (I/O); also elsewhere on the board
VD1: U5.15 (I/O); also elsewhere on the board
VD2: U5.10 (I/O); also elsewhere on the board
VD3: U5.9 (I/O); also elsewhere on the board
VD4: U5.11 (I/O); also elsewhere on the board
VD5: U5.12 (I/O); also elsewhere on the board
VD6: U5.16 (I/O); also elsewhere on the board
VD7: U5.18 (I/O); also elsewhere on the board
VRD: U5.27 (I/O); also elsewhere on the board
VWR: U5.39 (I/O); also elsewhere on the board
WR: U5.6 (I/O); also elsewhere on the board
blue: U5.57 (I/O); also elsewhere on the board
bright: U5.54 (I/O); also elsewhere on the board
green: U5.56 (I/O); also elsewhere on the board
red: U5.58 (I/O); also elsewhere on the board
sync: U5.55 (I/O); also elsewhere on the board

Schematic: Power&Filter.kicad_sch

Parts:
C4: 10uF 25V; CAPPRD200W50D500H1100; Mouser Part Number 667-ECA-1EM100B
C5: 22uF 16V; CAPPRD200W50D500H1100; Mouser Part Number 667-ECA-1EM100B
C8: 220uF 16V; CAPPRD200W50D500H1100
C9, C10, C11, C12, C13, C14, C15, C16, C17, C19, C20: 100nF; CAPRB250W50L400T250H550; Mouser Part Number 594-K104Z15Y5VF5TL2
D28: DF02M; DIP825W58P510L832H543Q4N; Mouser Part Number 621-DF02M
J3: ZX_48K_EDGE; ZX_BUS_B_TOP
J4: PJ-002A; CUI_PJ-002A
J17: Header 2x1; HARWIN_M20-9990246; PARTREV 14
U14: R-78E5.0-1.0; CONV_R-78E5.0-1.0; PARTREV 6

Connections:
+9V: C4.1 (+), D28.1 (+), J3.A4 (+9), U14.1 (+VIN)
+12V: J3.B22 (+12)
-5V: J3.B20 (-5)
-12V: J3.B23 (-12)
A0: J3.A9 (A0); also elsewhere on the board
A1: J3.A10 (A1); also elsewhere on the board
A2: J3.A11 (A2); also elsewhere on the board
A3: J3.A12 (A3); also elsewhere on the board
A4: J3.A24 (A4); also elsewhere on the board
A5: J3.A23 (A5); also elsewhere on the board
A6: J3.A22 (A6); also elsewhere on the board
A7: J3.A21 (A7); also elsewhere on the board
A8: J3.B26 (A8); also elsewhere on the board
A9: J3.A27 (A9); also elsewhere on the board
A10: J3.B27 (A10); also elsewhere on the board
A11: J3.A28 (A11); also elsewhere on the board
A12: J3.A2 (A12); also elsewhere on the board
A13: J3.B2 (A13); also elsewhere on the board
A14: J3.A1 (A14); also elsewhere on the board
A15: J3.B1 (A15); also elsewhere on the board
BUSAK: J3.A26 (BUSACK); also elsewhere on the board
BUSRQ: J3.A19 (BUSRQ); also elsewhere on the board
CLKB: J3.A8 (CLOCK); also elsewhere on the board
D0: J3.B6 (D0); also elsewhere on the board
D1: J3.B7 (D1); also elsewhere on the board
D2: J3.B8 (D2); also elsewhere on the board
D3: J3.B11 (D3); also elsewhere on the board
D4: J3.B12 (D4); also elsewhere on the board
D5: J3.B10 (D5); also elsewhere on the board
D6: J3.B9 (D6); also elsewhere on the board
D7: J3.B3 (D7); also elsewhere on the board
GND: C4.2 (-), C5.2 (-), C8.2, C9.2 (-), C10.2 (-), C11.2 (-), C12.2 (-), C13.2 (-), C14.2 (-), C15.2 (-), C16.2 (-), C17.2 (-), C19.2 (-), C20.2 (-), D28.2 (-), J3.A6 (GND), J3.A7 (GND), J3.A14 (GND), J17.2, U14.2 (GND); also elsewhere on the board
HALT: J3.B15 (HALT); also elsewhere on the board
INT: J3.B13 (INT); also elsewhere on the board
IORQ: J3.B17 (IOREQ); also elsewhere on the board
IORQULA: J3.A13 (IORQGE); also elsewhere on the board
M1: J3.B24 (M1); also elsewhere on the board
MREQ: J3.B16 (MREQ); also elsewhere on the board
NMI: J3.B14 (NMI); also elsewhere on the board
unnamed: D28.3 (~_1), J4.1
unnamed: D28.4 (~_2), J4.2, J4.3
RD: J3.B18 (RD); also elsewhere on the board
RFSH: J3.B25 (RFSH); also elsewhere on the board
ROMCS: J3.A25 (ROMCS); also elsewhere on the board
RST: J3.A20 (RESET); also elsewhere on the board
VCC: C5.1 (+), C8.1, C9.1 (+), C10.1 (+), C11.1 (+), C12.1 (+), C13.1 (+), C14.1 (+), C15.1 (+), C16.1 (+), C17.1 (+), C19.1 (+), C20.1 (+), J3.A3 (+5), J17.1, U14.3 (+VOUT); also elsewhere on the board
WAIT: J3.B21 (WAIT); also elsewhere on the board
WR: J3.B19 (WR); also elsewhere on the board

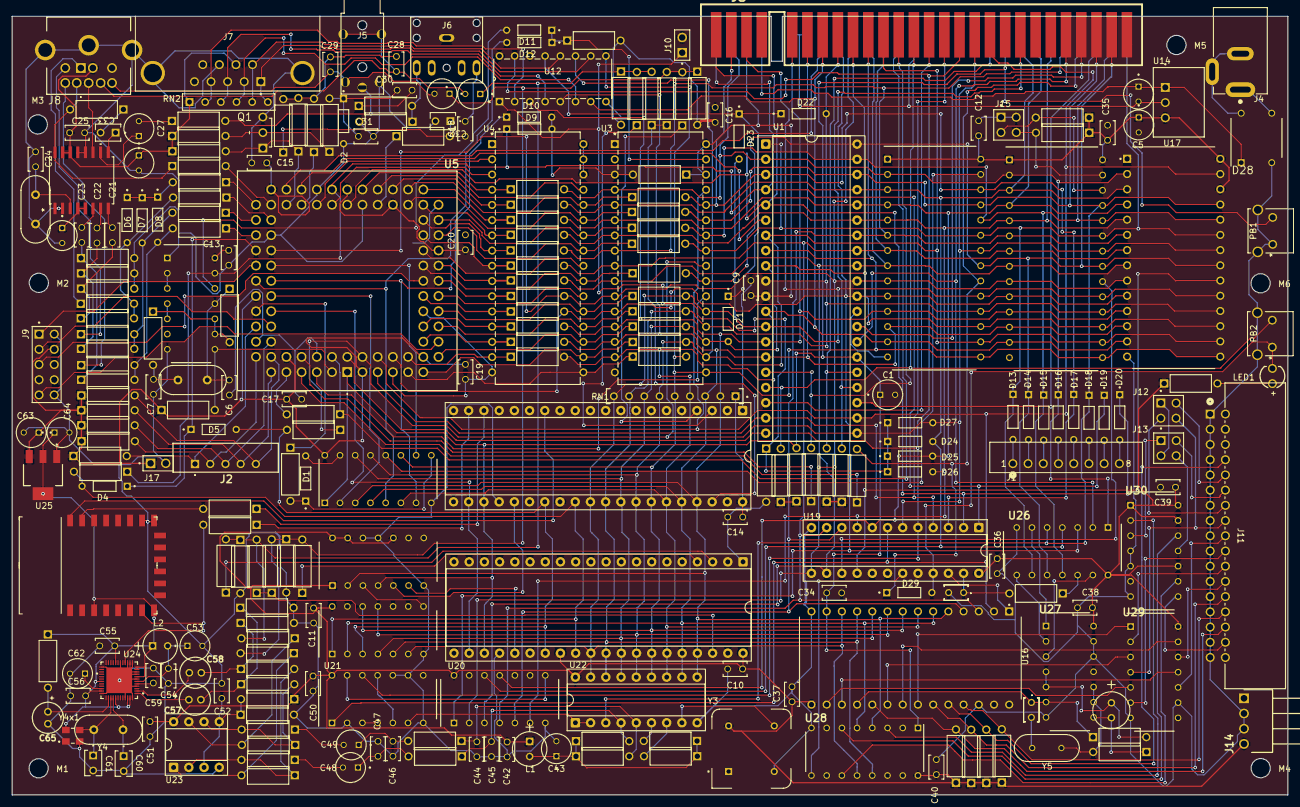
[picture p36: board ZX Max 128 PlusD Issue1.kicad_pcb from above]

Board: 2 copper layers, 213.0 x 130.0 mm, 272 parts (0 on the bottom side), 248 nets.

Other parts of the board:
C2, C3: 10uF 25V; CAPPRD200W50D500H1100
D4, D5: 1N4148; DIOAD753W49L380D172B
J5: AV Jack; PJ-322A
R57, R58, R81, R82: 470R; STA_CF14_STP
R59, R62, R63, R64, R65, R68, R69, R70: 1K00; STA_CF14_STP
R60, R61, R66, R67: 2K20; STA_CF14_STP
U8, U9: AY-3-8910; Z80_Socket
U10: CD74HC30E; DIP794W53P254L1930H508Q14N
U11: 74HC74; DIP794W53P254L1930H508Q14N
U15: ESP8266-12E; WIFI_Module_ESP8266_12E

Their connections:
+3V3D: U15.3 (EN), U15.8 (VCC); also elsewhere on the board
A14: R57.1; also elsewhere on the board
A-AY: R59.1, U8.4 (CHANNEL_A)
A-AY2: R65.1, U9.4 (CHANNEL_A)
AY1: U8.25 (A8), U11.5 (Q)
AY2: U9.25 (A8), U11.6 (~Q)
Audio-L: C3.2 (-), J5.3; also elsewhere on the board
Audio-R: C2.2 (-), J5.4; also elsewhere on the board
B-AY: R62.1, U8.3 (CHANNEL_B)
B-AY2: R68.1, U9.3 (CHANNEL_B)
BC1: D4.A, R57.2, U8.29 (BC1), U9.29 (BC1), U10.1
BDIR: D5.A, R58.2, U8.27 (BDIR), U9.27 (BDIR), U10.3
C-AY: R60.1, R61.1, U8.38 (CHANNEL_C)
CLKAY: U8.22 (CLK), U9.22 (CLK); also elsewhere on the board
Comp: J5.1; also elsewhere on the board
D0: U8.37 (DA0), U9.37 (DA0), U11.2 (D); also elsewhere on the board
D1: U8.36 (DA1), U9.36 (DA1), U10.2; also elsewhere on the board
D2: U8.35 (DA2), U9.35 (DA2); also elsewhere on the board
D3: U8.34 (DA3), U9.34 (DA3), U10.12; also elsewhere on the board
D4: U8.33 (DA4), U9.33 (DA4), U10.11; also elsewhere on the board
D5: U8.32 (DA5), U9.32 (DA5), U10.4; also elsewhere on the board
D6: U8.31 (DA6), U9.31 (DA6), U10.5; also elsewhere on the board
D7: U8.30 (DA7), U9.30 (DA7), U10.6; also elsewhere on the board
GND: J5.2, R63.2, R64.2, R69.2, R70.2, U8.1 (VSS), U8.24 (~A9), U9.1 (VSS), U9.24 (~A9), U10.7 (GND), U11.7 (GND), U11.11 (C), U11.12 (D), U15.15 (GND), U15.16 (TXD2/IO15); also elsewhere on the board
IN4: U8.14 (IOA7), U15.22 (TXD0/TXD)
L-in: C3.1 (+), R61.2, R62.2, R64.1, R67.2, R68.2, R70.1; also elsewhere on the board
MIDI: R81.2, U15.7 (MOSI/IO13); also elsewhere on the board
unnamed: R66.1, R67.1, U9.38 (CHANNEL_C)
unnamed: U10.8, U11.3 (C)
unnamed: R82.2, U15.21 (RXD0/RXD)
OUT3: R81.1, U8.19 (IOA2)
OUT4: R82.1, U8.18 (IOA3)
PSG: D4.K, D5.K; also elsewhere on the board
R-in: C2.1 (+), R59.2, R60.2, R63.1, R65.2, R66.2, R69.1; also elsewhere on the board
RD: R58.1; also elsewhere on the board
RST: U8.23 (~RESET), U9.23 (~RESET), U11.4 (~S); also elsewhere on the board
VCC: U8.28 (BC2), U8.40 (VCC), U9.28 (BC2), U9.40 (VCC), U10.14 (VCC), U11.1 (~R), U11.10 (~S), U11.13 (~R), U11.14 (VCC); also elsewhere on the board

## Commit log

2026-02-05 Initial upload of KiCAD 9 files for ZX Max PlusD Issue 1 PCB
    Initial upload of KiCAD 9 files for ZX Max PlusD Issue 1 PCB, Folders for BOM, MOD, STEP and SYM to follow.
    [CPU-ROM-RAM.kicad_sch, DivMMC.kicad_sch, EPM7128S.kicad_sch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]
2026-02-05 Add files via upload
    Initial upload of KiCAD 9 files for ZX Max PlusD Issue 1 PCB, Folders for BOM and MOD. STEP and SYM to follow.
2026-02-05 Add files via upload
    Initial upload of KiCAD 9 files for ZX Max PlusD Issue 1 PCB, Folder for SYM. STEP to follow.
2026-02-05 Add files via upload
    Initial upload of KiCAD 9 files for ZX Max PlusD Issue 1 PCB, Folder STEP part 1.
    [9Pin D MRA Assmannn A-DS_09_A_KG-T4S.step, AT28C64B-15PU.step, CD74HC366E.stp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]
2026-02-05 Add files via upload
    Initial upload of KiCAD 9 files for ZX Max PlusD Issue 1 PCB, Folder STEP part 2.
    [1N4148.stp, 84-PLCC_ALR.step, 9Pin MiniDIN KMDGX-9S-BS-1.stp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]
2026-02-05 Add README with project overview and warnings
    Added a README file with project details and warnings about PCB layout accuracy.
2026-02-06 Delete Step directory
    Appears Step files from Samtec are not allowed to be shared.
    [1N4148.stp, 84-PLCC_ALR.step, 9Pin D MRA Assmannn A-DS_09_A_KG-T4S.step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]
2026-07-05 Delete Mod directory
    Removed old folder to replace with correct kicad_mod files
2026-07-05 Delete Sym directory
    Deleted to replace with correct kicad_sym files
2026-07-05 Add files via upload
    Upload of Kicad 10 files, replacing those from Kicad 9.
    [CPU-ROM-RAM.kicad_sch, EPM7128S.kicad_sch, Joystick.kicad_sch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]
2026-07-05 Add files via upload
    This is a recreation of the ZX Max 128 Plus D 5 PCB as designed by DonSuperfo but done in KiCAD 10.
    This was only done in order to create an interactive BOM (in the BOM folder) to assist in the assembling of the PCB.
    The KiCAD schematics 'should' be correct but nothing should be assumed as correct without checking with the original schematic and PCB layout.
    Use at your own risk.
    [9Pin D MRA Assmannn A-DS_09_A_KG-T4S.step, 9Pin MiniDIN KMDGX-9S-BS-1_A1.IGS, ADI724JRZ RW_16_ADI.step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]
2026-07-05 Revise README for KiCAD version and warnings
    Updated KiCAD version from 9 to 10 and clarified warnings about PCB layout correctness.
2026-07-26 Update README with assembly and part number details
    Added notes about part numbers and ordering PCBs.

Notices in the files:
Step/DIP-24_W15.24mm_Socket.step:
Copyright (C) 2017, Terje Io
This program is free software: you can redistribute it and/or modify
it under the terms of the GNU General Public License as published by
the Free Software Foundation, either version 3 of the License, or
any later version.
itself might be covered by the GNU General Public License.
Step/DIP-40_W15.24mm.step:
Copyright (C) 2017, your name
